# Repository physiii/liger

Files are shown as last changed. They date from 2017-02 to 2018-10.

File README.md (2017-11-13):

# ESP32 Room Sensor

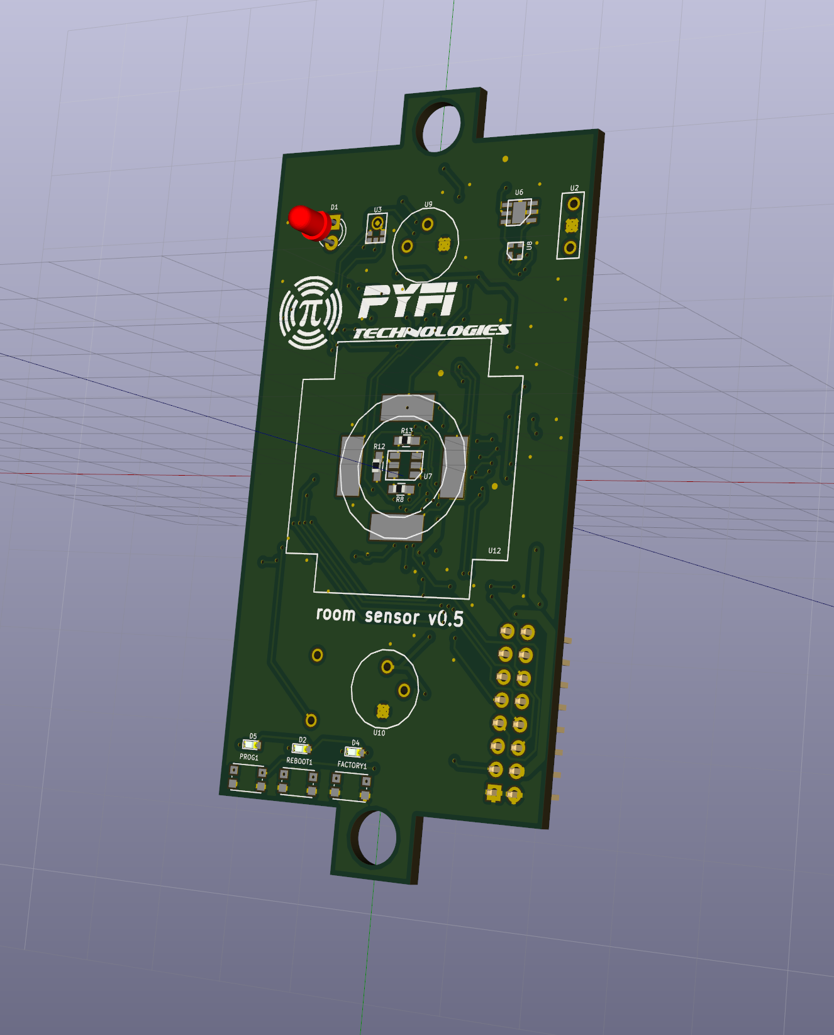
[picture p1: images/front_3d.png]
front


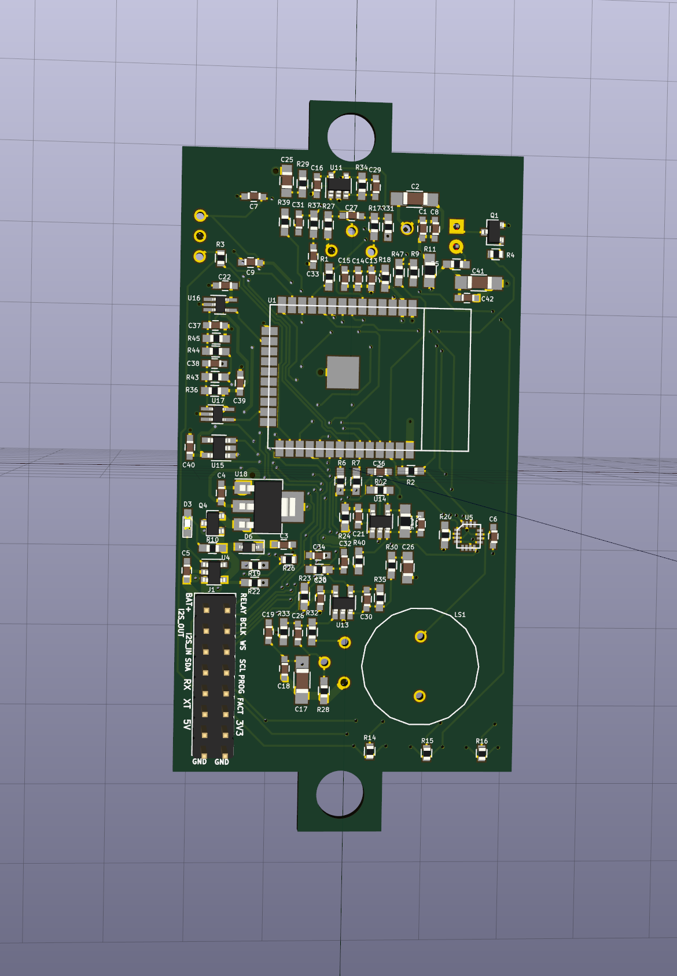
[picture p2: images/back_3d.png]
back


back

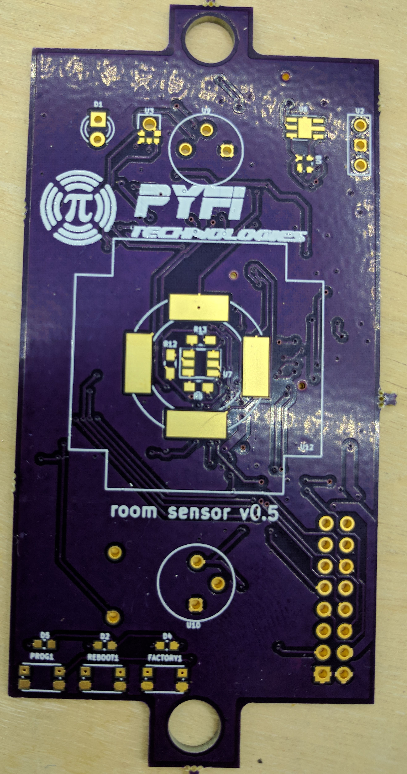
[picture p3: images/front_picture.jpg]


## Schematic Overview
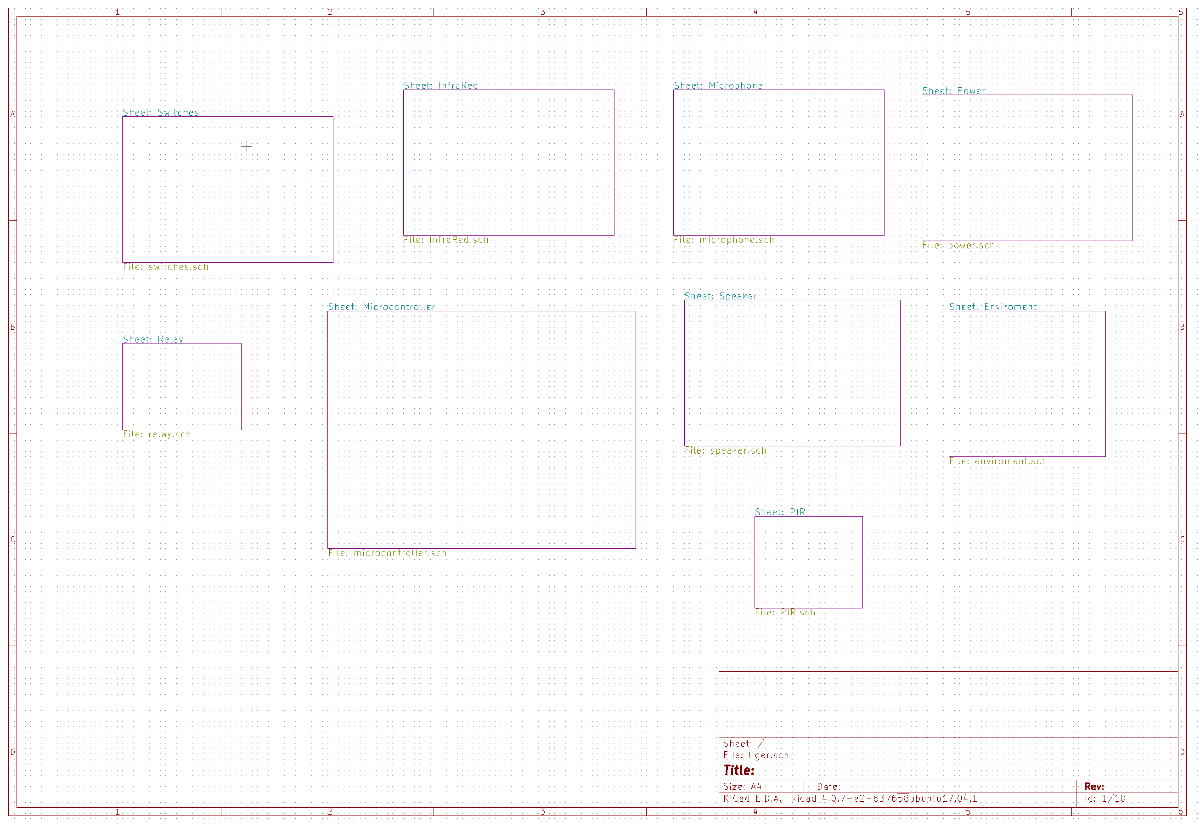
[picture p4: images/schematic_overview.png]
schematic overview


## Motion (PIR) Component
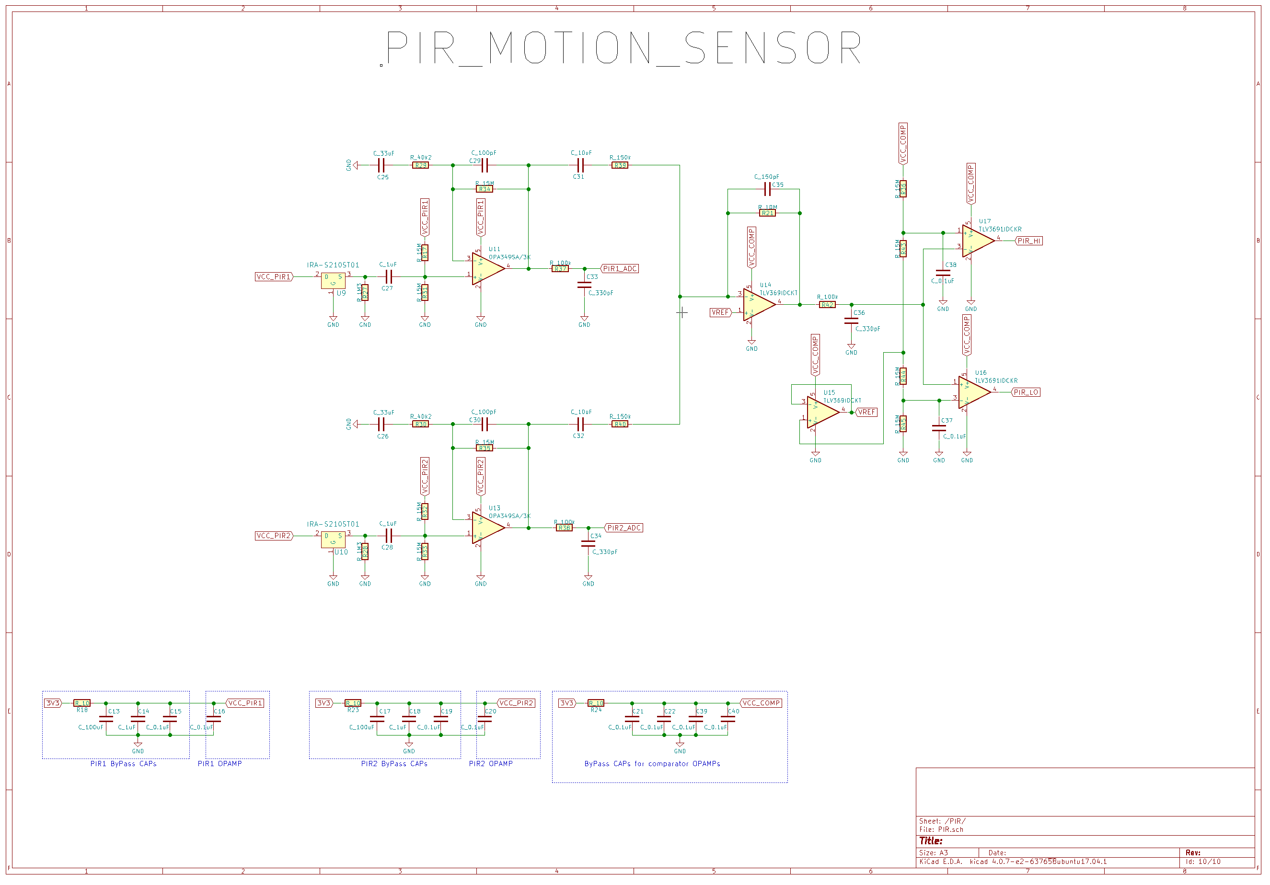
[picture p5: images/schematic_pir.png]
motion


## Features
Motion detection<br>
Audio detection<br>
Media control<br>
Security mode<br>
Light level<br>

## Sensor components
I2S Microphone<br>
Speaker<br>
IR Transmitter<br>
IR Receiver<br>
directional soft button<br>
I2C luminosity<br>
Dual PIR for animal vs human distrinction<br>
Ultrasonic (optional)<br>
Temperature/Humidity<br>

## Applications
Building Automation<br>
Motion Detection<br>
Intrusion Detection<br>
Occupancy Detector<br>
Room Monitors<br>
Pet Detection<br>
Fire Detection<br>
Falling Person Detection<br>

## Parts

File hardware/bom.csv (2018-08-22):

Reference Type | Quantity | Reference | Value | Footprint | Datasheet | Part Number
BT | 1 | BT1, | 18650_Battery_Cell_1043 | Battery:BatteryHolder_Keystone_1042_1x18650 | https://www.digikey.com/product-detail/en/keystone-electronics/1043/36-1043-ND/2745669 | 36-1043-ND
C | 4 | C5,C6,C11,C10, | C_0.1uF | Capacitor_SMD:C_0603_1608Metric_Pad1.05x0.95mm_HandSolder | https://www.digikey.com/product-detail/en/tdk-corporation/C1608X8R1H104K080AB/445-8818-1-ND/3248223 | C1608X8R1H104K080AB
C | 6 | C4,C2,C8,C7,C9,C12, | C_1uF | Capacitor_SMD:C_0603_1608Metric_Pad1.05x0.95mm_HandSolder | https://www.digikey.com/product-detail/en/tdk-corporation/CGA3E1X7R1C105M080AC/445-12540-1-ND/3954206 | CGA3E1X7R1C105M080AC
C | 2 | C3,C1, | C_10uF | Capacitor_SMD:C_0603_1608Metric_Pad1.05x0.95mm_HandSolder | https://www.digikey.com/product-detail/en/samsung-electro-mechanics/CL10A106MP8NNNC/1276-1871-1-ND/3889957 | CL10A106MP8NNNC
D | 1 | D6, | D_Schottky-BAT20JFILM | Diode_SMD:D_SOD-323_HandSoldering | https://www.digikey.com/product-detail/en/stmicroelectronics/BAT20JFILM/497-3381-1-ND/669138 | BAT20JFILM
D | 1 | D1, | LED | LED_THT:LED_D3.0mm | http://www.mouser.com/ds/2/149/QED123-890063.pdf | QED123
D | 3 | D2,D4,D5, | LED-0603-G | LED_SMD:LED_0603_1608Metric_Pad1.05x0.95mm_HandSolder | https://www.digikey.com/product-detail/en/rohm-semiconductor/SML-D12M8WT86/511-1578-1-ND/1641810 | SML-D12M8WT86
D | 1 | D3, | LED-GREEN-LTST-C191GKT | LED_SMD:LED_0603_1608Metric_Pad1.05x0.95mm_HandSolder | https://www.digikey.com/product-detail/en/lite-on-inc/LTST-C191GKT/160-1443-1-ND/386828 | LTST-C191GKT
D | 1 | D7, | WS2812B | LED_SMD:LED_WS2812B_PLCC4_5.0x5.0mm_P3.2mm | https://cdn-shop.adafruit.com/datasheets/WS2812B.pdf
FACTORY | 1 | FACTORY1, | SW_PUSH | Button_Switch_SMD:SW_SPST_KMR2 | http://www.mouser.com/ds/2/60/KMR2_9aug12-25127.pdf | KMR211NG LFS
J | 1 | J1, | Conn_02x08_Odd_Even | Connector_PinHeader_2.54mm:PinHeader_2x08_P2.54mm_Vertical
LS | 1 | LS1, | speaker-CVS-1508 | open-automation:speaker-1508 | http://www.cui.com/product/resource/cvs-1508.pdf | CVS-1508
PROG | 1 | PROG1, | SW_PUSH | Button_Switch_SMD:SW_SPST_KMR2 | http://www.mouser.com/ds/2/60/KMR2_9aug12-25127.pdf | KMR211NG LFS
Q | 1 | Q4, | PMOS-DMG3413L | Package_TO_SOT_SMD:SOT-23 | https://www.digikey.com/product-detail/en/diodes-incorporated/DMG3413L-7/DMG3413L-7DICT-ND/5218387 | DMG3413L-7
Q | 1 | Q1, | Q_NPN_BEC | Package_TO_SOT_SMD:SOT-23 | http://www.onsemi.com/pub/Collateral/MMBT3904LT1-D.PDF | MMBT3904LT1GOSCT-ND
R | 1 | R5, | 36 | Resistor_SMD:R_0603_1608Metric_Pad1.05x0.95mm_HandSolder | http://www.yageo.com.tw/exep/pages/download/literatures/PYu-R_INT-thick_7.pdf | RC0603JR-0736RL
R | 3 | R7,R1,R11, | R_47.5 | Resistor_SMD:R_0603_1608Metric_Pad1.05x0.95mm_HandSolder | https://www.digikey.com/product-detail/en/yageo/RC0603FR-0747R5L/311-47.5HRCT-ND/730201 | RC0603FR-0747R5L
R | 6 | R3,R4,R10,R15,R16,R14, | R_1k | Resistor_SMD:R_0603_1608Metric_Pad1.05x0.95mm_HandSolder | https://www.digikey.com/product-detail/en/yageo/RC0603JR-071KL/311-1.0KGRCT-ND/729624 | RC0603JR-071KL
R | 1 | R19, | R_2k | Resistor_SMD:R_0603_1608Metric_Pad1.05x0.95mm_HandSolder | https://www.digikey.com/product-detail/en/yageo/RC0603JR-072KL/311-2.0KGRCT-ND/729673 | RC0603JR-072KL
R | 4 | R6,R2,R22,R26, | R_10k | Resistor_SMD:R_0603_1608Metric_Pad1.05x0.95mm_HandSolder | https://www.digikey.com/product-detail/en/yageo/RC0603JR-0710KL/311-10KGRCT-ND/729647 | RC0603JR-0710KL
R | 4 | R9,R17,R18,R20, | R_100k | Resistor_SMD:R_0603_1608Metric_Pad1.05x0.95mm_HandSolder | https://www.digikey.com/product-detail/en/yageo/RC0603JR-07100KL/311-100KGRCT-ND/729645 | RC0603JR-07100KL
REBOOT | 1 | REBOOT1, | SW_PUSH | Button_Switch_SMD:SW_SPST_KMR2 | http://www.mouser.com/ds/2/60/KMR2_9aug12-25127.pdf | KMR211NG LFS
U | 1 | U9, | AP2112 | Package_TO_SOT_SMD:SOT-23-5_HandSoldering | https://www.digikey.com/product-detail/en/diodes-incorporated/AP2112K-3.3TRG1/AP2112K-3.3TRG1DICT-ND/4505257 | AP2112K-3.3TRG1
U | 1 | U10, | EKMC1601112 | open-automation:EKMC1601112 | https://www.digikey.com/products/en?keywords=EKMC1601112 | EKMC1601112
U | 1 | U1, | ESP-WROOM-32 | open-automation:ESP-WROOM-32 | http://espressif.com/sites/default/files/documentation/esp-wroom-32_datasheet_en.pdf
U | 1 | U2, | IR-RX-TSOP34438 | open-automation:TSOP75338TR | https://www.digikey.com/product-detail/en/vishay-semiconductor-opto-division/TSOP75338TR/TSOP75338CT-ND/6596741 | TSOP75338TR
U | 1 | U5, | MAX98357AETE+T | open-automation:MAX98357A | https://www.digikey.com/product-detail/en/maxim-integrated/MAX98357AETE-T/MAX98357AETE-TCT-ND/7603777 | MAX98357AETE+T
U | 1 | U4, | MCP73831T | Package_TO_SOT_SMD:SOT-23-5_HandSoldering | https://www.digikey.com/product-detail/en/microchip-technology/MCP73831T-2ACI-OT/MCP73831T-2ACI-OTCT-ND/1979802 | MCP73831T-2ACI/OT
U | 1 | U6, | SI7020-A20 | open-automation:SI7020-A20 | https://www.digikey.com/product-detail/en/silicon-labs/SI7020-A20-GM1R/336-3596-1-ND/5823452 | SI7020-A20-GM1R
U | 1 | U3, | SPH0645LM4H-B | open-automation:SPH0645LM4H-B | https://www.digikey.com/product-detail/en/knowles/SPH0645LM4H-B/423-1405-6-ND/5332436 | SPH0645LM4H-B
U | 1 | U8, | TSL45315CL | open-automation:LIGHT-SENSOR-TSL45315CL | https://www.digikey.com/product-detail/en/ams/TSL45315CL/TSL45315-CLCT-ND/3095326 | TSL45315CL
U | 1 | U12, | soft-button-4x | open-automation:soft-button-4

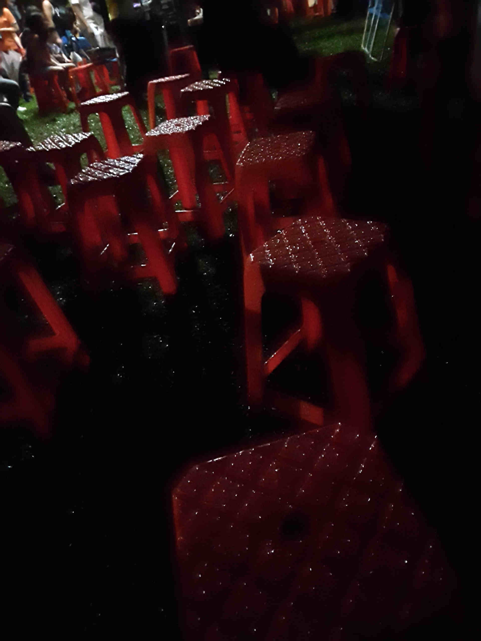
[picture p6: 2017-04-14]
lws-esp32-test-server-demos/components/libwebsockets/plugins/generic-sessions/assets/seats.jpg

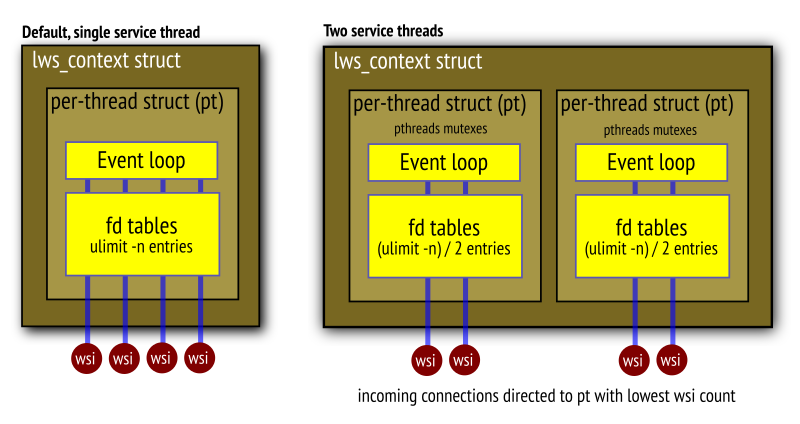
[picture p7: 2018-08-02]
lws-esp32-test-server-demos/components/libwebsockets/doc-assets/lws-smp-ov.png

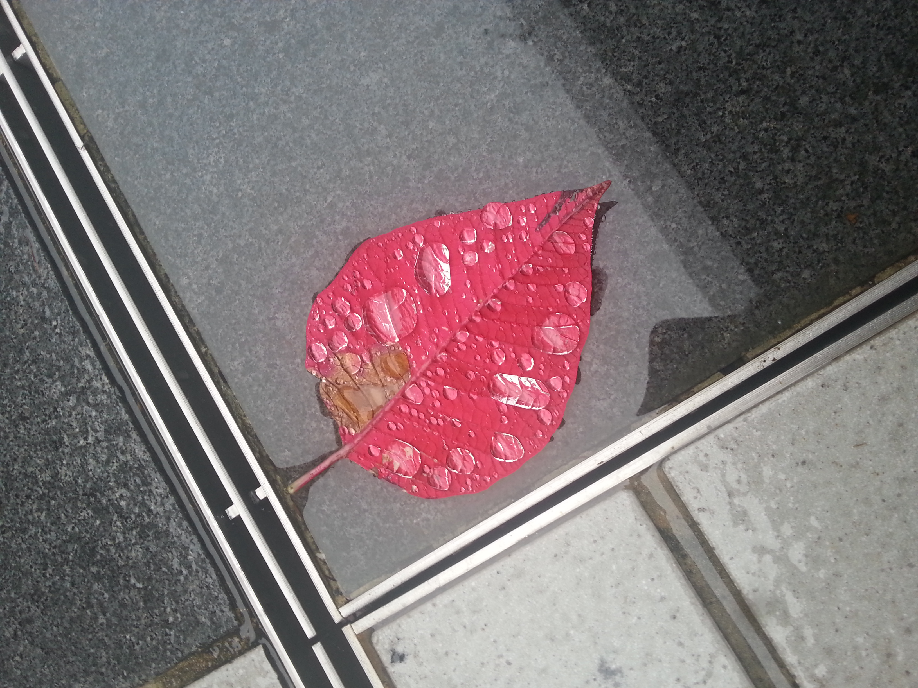
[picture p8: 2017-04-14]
lws-esp32-test-server-demos/components/libwebsockets/minimal-examples/http-server/minimal-http-server-eventlib-demos/mount-origin/leaf.jpg

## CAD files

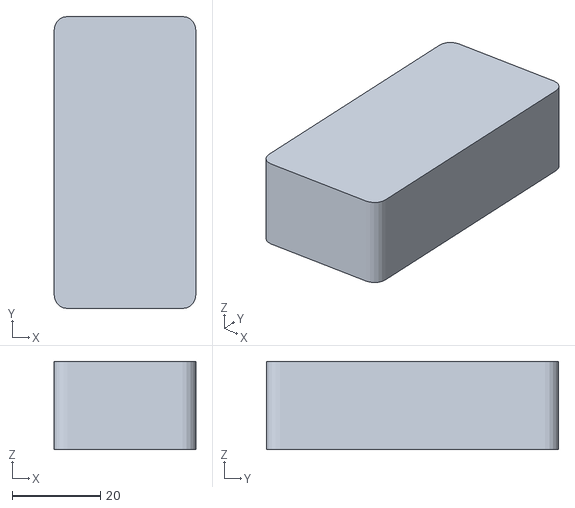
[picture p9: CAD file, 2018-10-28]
model/test_block.stl
32.0 x 66.0 x 20.0

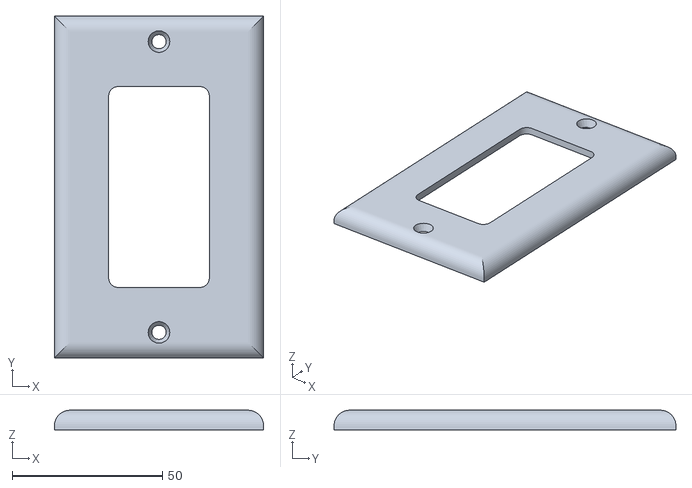
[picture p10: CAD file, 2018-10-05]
model/GFCI_WallPlate_SingleGang.stl
69.6 x 113.8 x 6.54

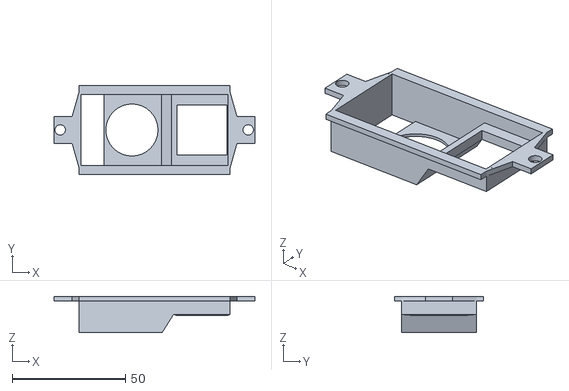
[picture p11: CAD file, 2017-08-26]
model/liger.stl
88.7 x 39.3 x 16.0

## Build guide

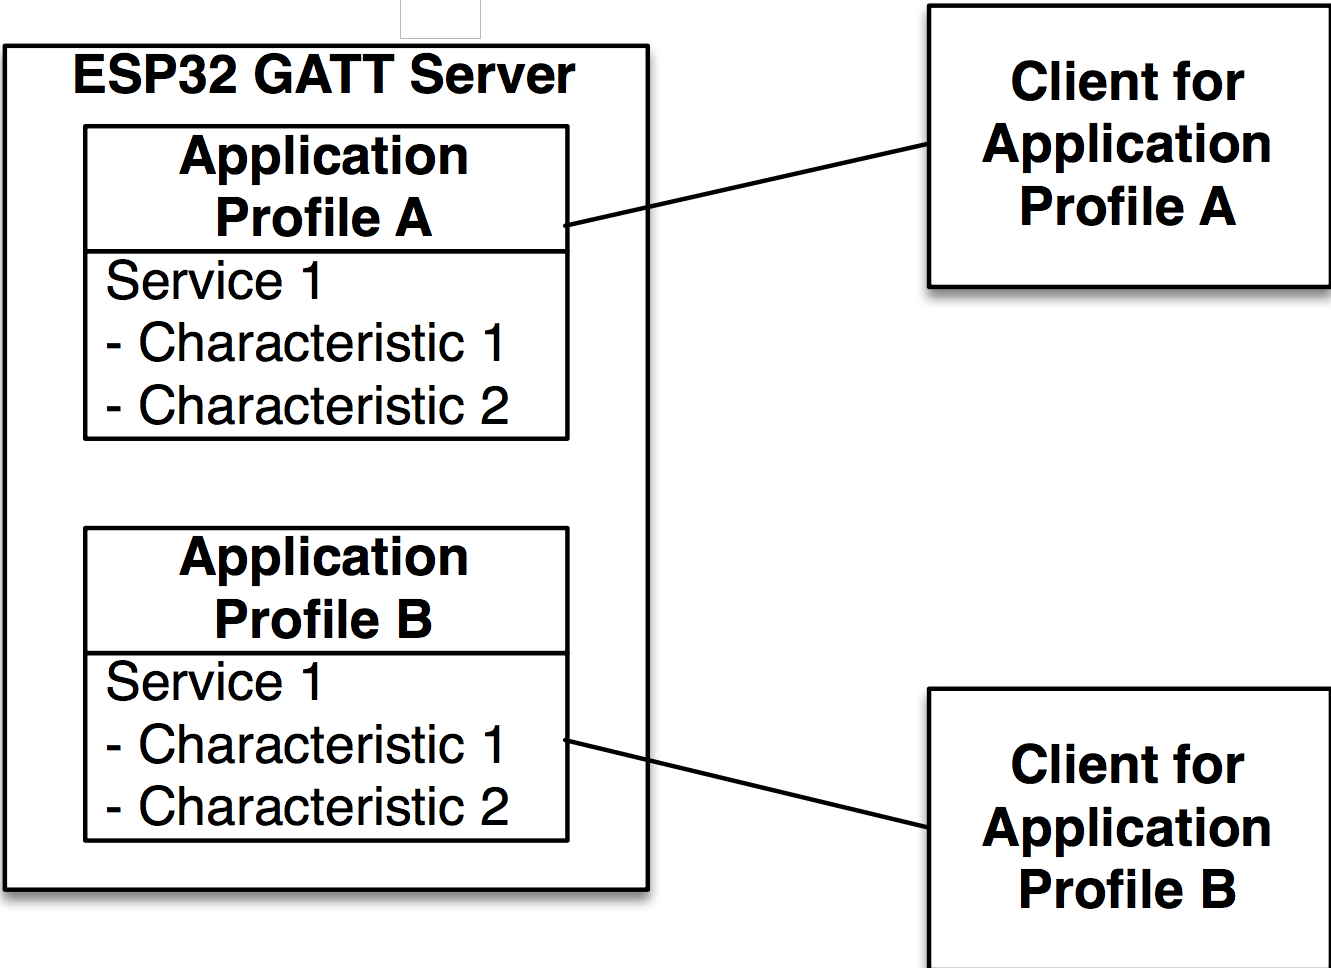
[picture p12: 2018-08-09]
code/bt_server/tutorial/image/GATT_Server_Figure_1.png

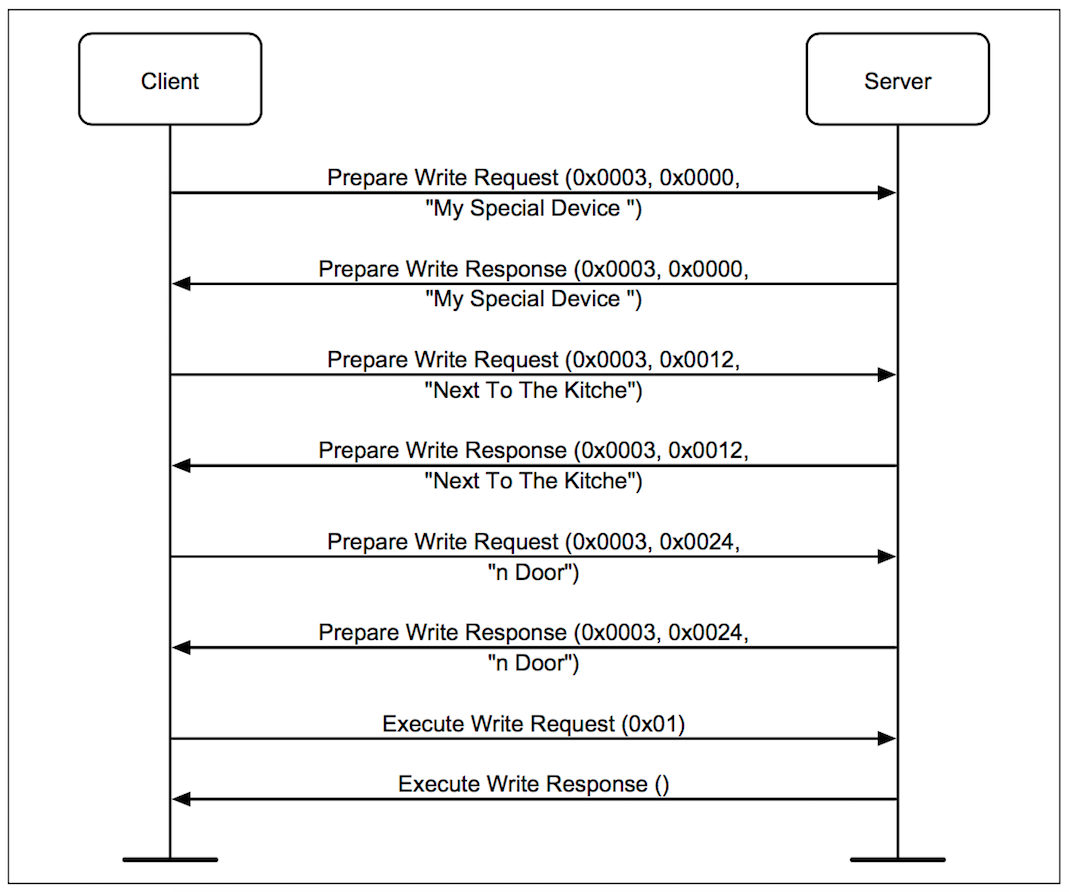
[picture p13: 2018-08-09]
code/bt_server/tutorial/image/GATT_Server_Figure_2.png

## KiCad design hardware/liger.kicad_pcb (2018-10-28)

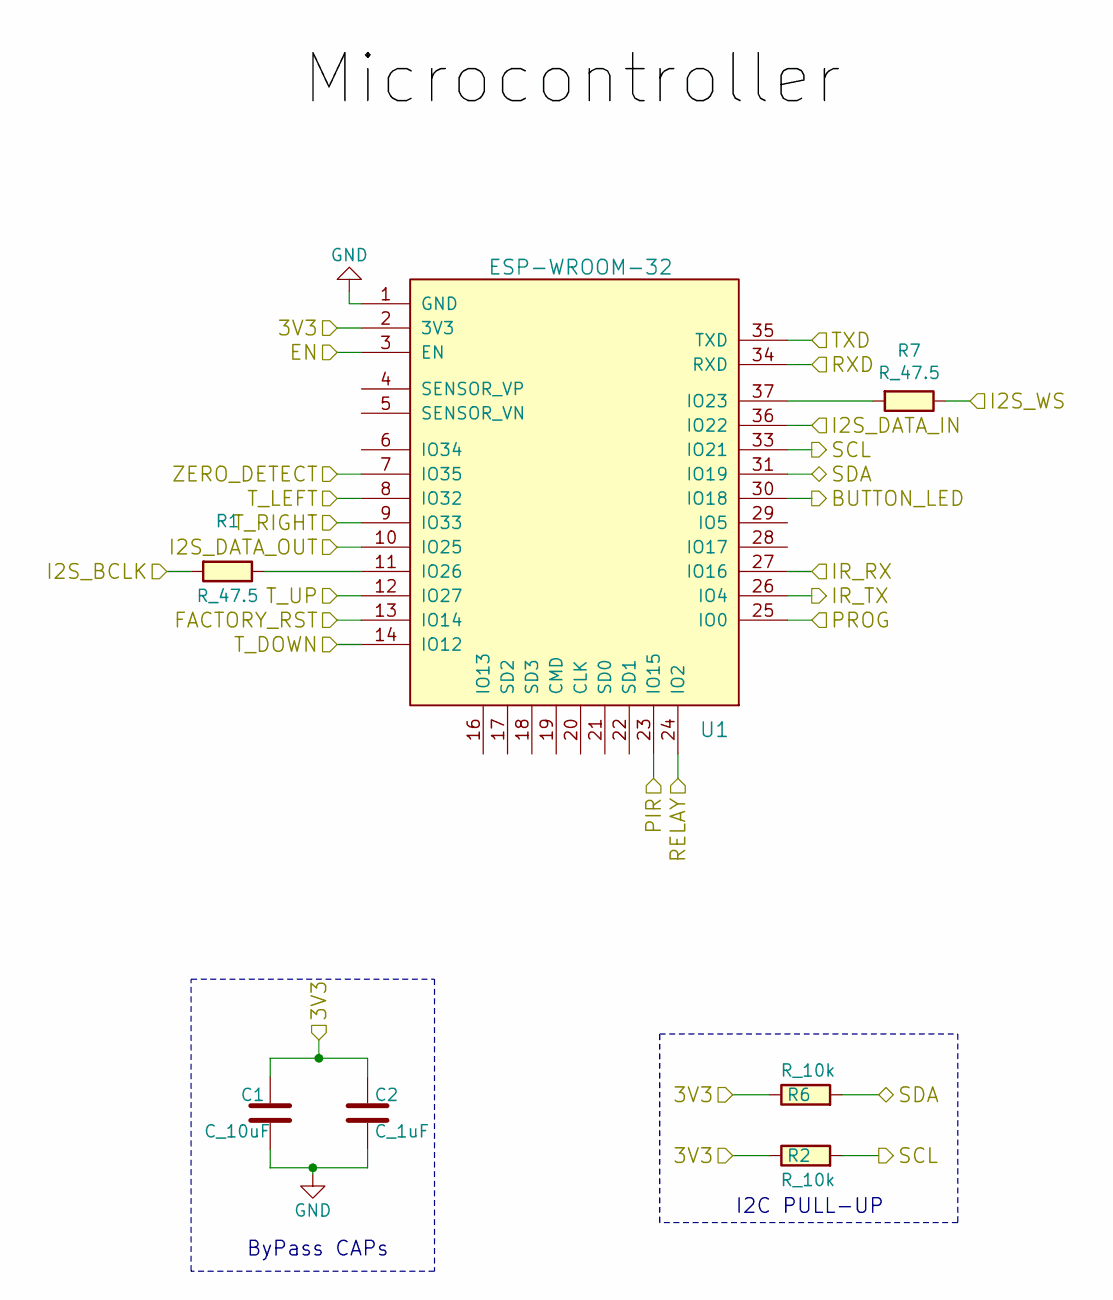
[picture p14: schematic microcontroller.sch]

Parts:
C1: C_10uF; C_0603_1608Metric_Pad1.05x0.95mm_HandSolder; Part Number CL10A106MP8NNNC
C2: C_1uF; C_0603_1608Metric_Pad1.05x0.95mm_HandSolder; Part Number CL10B105KP8NNNC
R1, R7: R_47.5; R_0603_1608Metric_Pad1.05x0.95mm_HandSolder; Part Number ERJ-3EKF47R5V
R2, R6: R_10k; R_0603_1608Metric_Pad1.05x0.95mm_HandSolder; Part Number MCT06030C1002FP500
U1: ESP-WROOM-32

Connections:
/3V3: C1.1, C2.1, R2.1, R6.1, U1.2 (3V3); also elsewhere on the board
/BUTTON_LED: U1.30 (IO18); also elsewhere on the board
/EN: U1.3 (EN); also elsewhere on the board
/FACTORY_RST: U1.13 (IO14); also elsewhere on the board
/I2S_BCLK: R1.2; also elsewhere on the board
/I2S_DATA_IN: U1.36 (IO22); also elsewhere on the board
/I2S_DATA_OUT: U1.10 (IO25); also elsewhere on the board
/I2S_WS: R7.1; also elsewhere on the board
/IR_RX: U1.27 (IO16); also elsewhere on the board
/IR_TX: U1.26 (IO4); also elsewhere on the board
/PIR: U1.23 (IO15); also elsewhere on the board
/PROG: U1.25 (IO0); also elsewhere on the board
/RELAY: U1.24 (IO2); also elsewhere on the board
/RXD: U1.34 (RXD); also elsewhere on the board
/SCL: R2.2, U1.33 (IO21); also elsewhere on the board
/SDA: R6.2, U1.31 (IO19); also elsewhere on the board
/TXD: U1.35 (TXD); also elsewhere on the board
/T_DOWN: U1.14 (IO12); also elsewhere on the board
/T_LEFT: U1.8 (IO32); also elsewhere on the board
/T_RIGHT: U1.9 (IO33); also elsewhere on the board
/T_UP: U1.12 (IO27); also elsewhere on the board
/ZERO_DETECT: U1.7 (IO35); also elsewhere on the board
GND: C1.2, C2.2, U1.1 (GND); also elsewhere on the board
unnamed: R1.1, U1.11 (IO26)
unnamed: R7.2, U1.37 (IO23)

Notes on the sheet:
ByPass CAPs
I2C PULL-UP

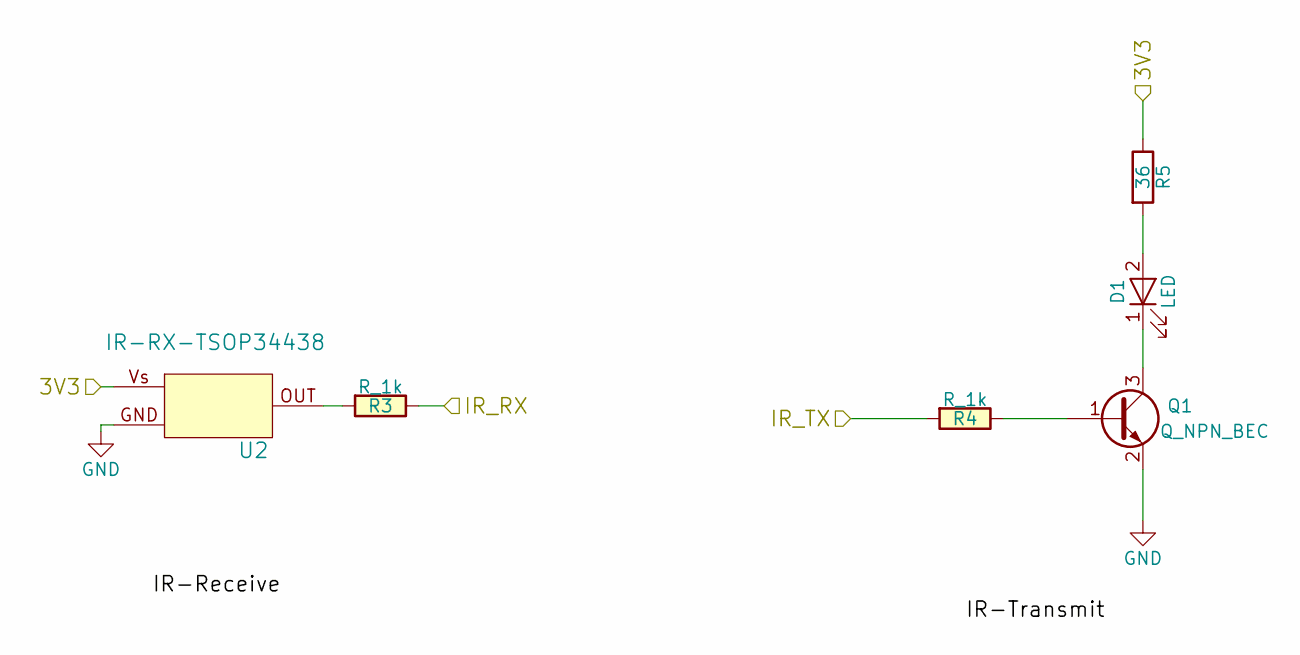
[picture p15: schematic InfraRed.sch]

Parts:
D1: LED; LED_D3.0mm; Part Number QED123
Q1: Q_NPN_BEC; SOT-23; Part Number MMBT3904-TP
R3, R4: R_1k; R_0603_1608Metric_Pad1.05x0.95mm_HandSolder; Part Number ESR03EZPJ102
R5: 36; R_0603_1608Metric_Pad1.05x0.95mm_HandSolder; Part Number RMCF0603FT36R0
U2: IR-RX-TSOP34438; TSOP75338TR; Part Number TSOP75338TR

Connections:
/3V3: R5.1, U2.Vs; also elsewhere on the board
/IR_RX: R3.1; also elsewhere on the board
/IR_TX: R4.2; also elsewhere on the board
GND: Q1.2 (E), U2.GND; also elsewhere on the board
unnamed: D1.1 (K), Q1.3 (C)
unnamed: D1.2 (A), R5.2
unnamed: Q1.1 (B), R4.1
unnamed: R3.2, U2.OUT

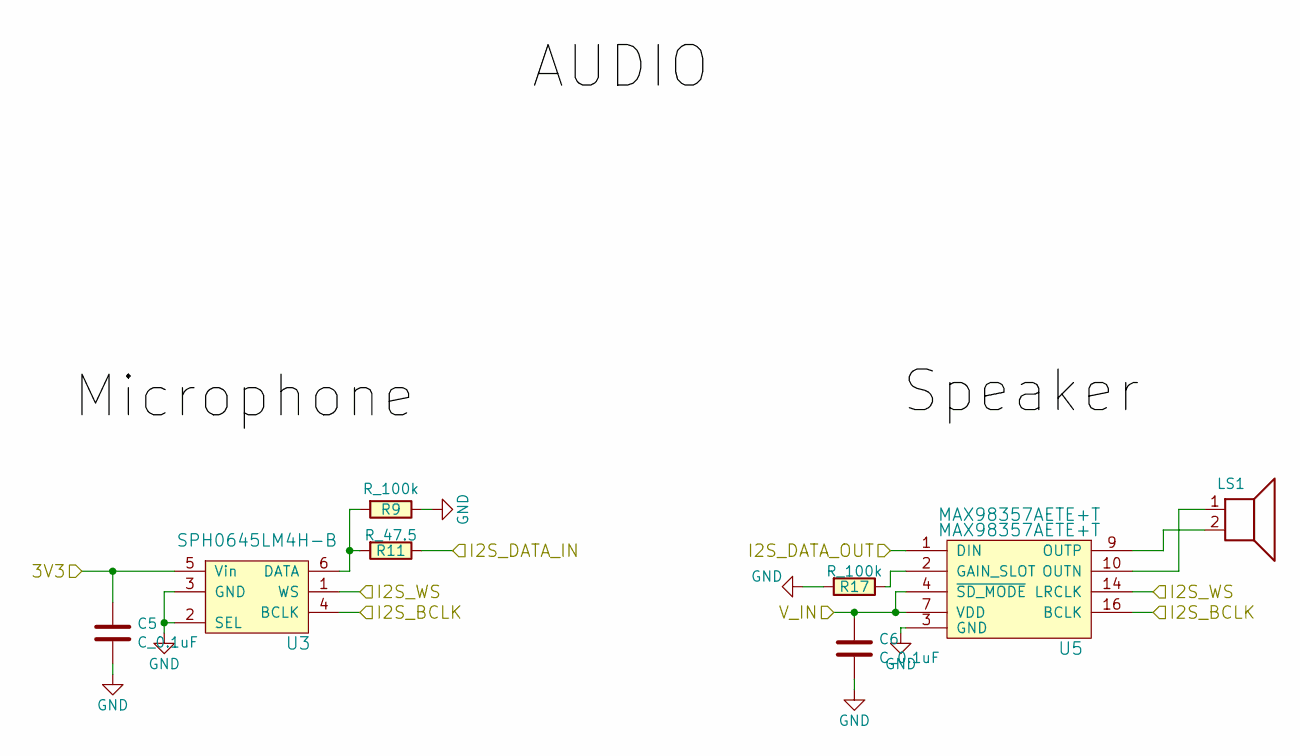
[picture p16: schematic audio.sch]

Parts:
C5, C6: C_0.1uF; C_0603_1608Metric_Pad1.05x0.95mm_HandSolder; Part Number CL10F104ZO8NNNC
LS1: speaker-CVS-1508; speaker-1508; Part Number CVS-1508
R9, R17: R_100k; R_0603_1608Metric_Pad1.05x0.95mm_HandSolder; Part Number ERA-3AEB104V
R11: R_47.5; R_0603_1608Metric_Pad1.05x0.95mm_HandSolder; Part Number ERJ-3EKF47R5V
U3: SPH0645LM4H-B; Part Number SPH0645LM4H-B
U5: MAX98357AETE+T; MAX98357A; Part Number MAX98357AETE+T

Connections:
/3V3: C5.1, U3.5 (Vin); also elsewhere on the board
/I2S_BCLK: U3.4 (BCLK), U5.16 (BCLK); also elsewhere on the board
/I2S_DATA_IN: R11.1; also elsewhere on the board
/I2S_DATA_OUT: U5.1 (DIN); also elsewhere on the board
/I2S_WS: U3.1 (WS), U5.14 (LRCLK); also elsewhere on the board
/V_IN: C6.1, U5.4 (~SD_MODE), U5.7 (VDD); also elsewhere on the board
GND: C5.2, C6.2, R9.1, R17.2, U3.2 (SEL), U3.3 (GND), U5.3 (GND); also elsewhere on the board
unnamed: LS1.1, U5.10 (OUTN)
unnamed: LS1.2, U5.9 (OUTP)
unnamed: R9.2, R11.2, U3.6 (DATA)
unnamed: R17.1, U5.2 (GAIN_SLOT)

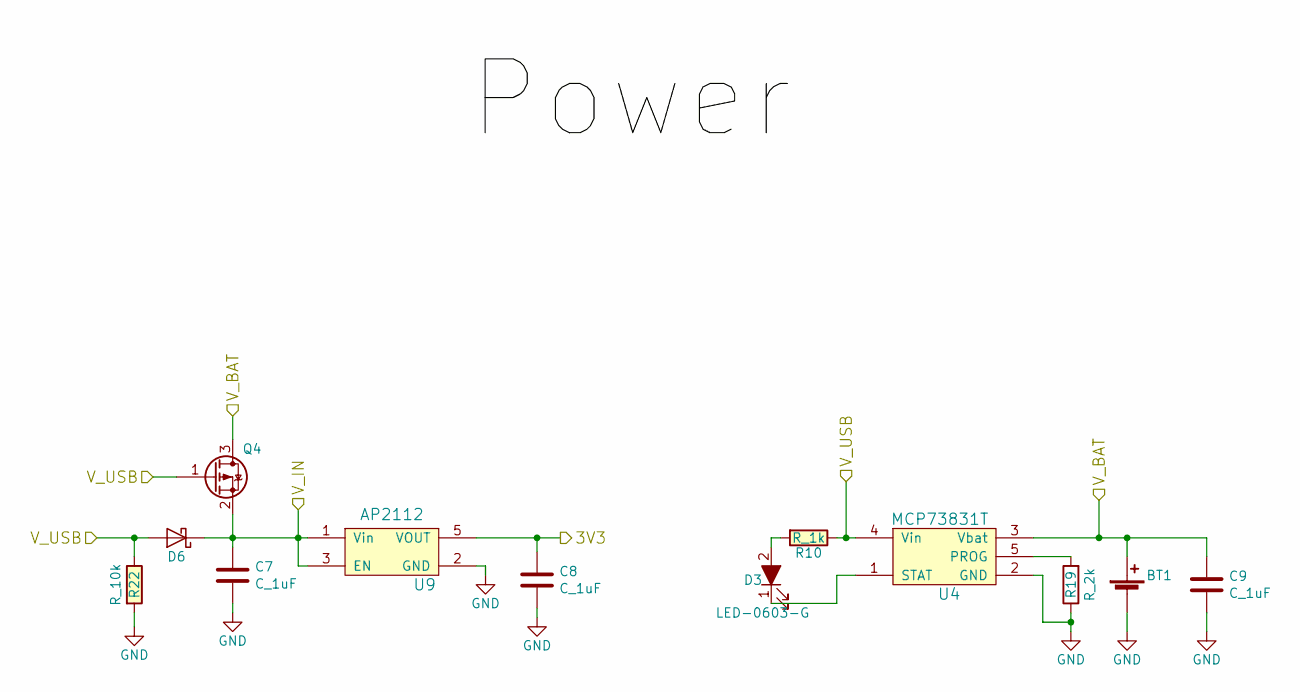
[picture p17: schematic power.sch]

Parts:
BT1: 18650_Battery_Cell_1043; BatteryHolder_Keystone_1042_1x18650; Part Number 36-1043-ND
C7, C8, C9: C_1uF; C_0603_1608Metric_Pad1.05x0.95mm_HandSolder; Part Number CL10B105KP8NNNC
D3: LED-0603-G; LED_0603_1608Metric_Pad1.05x0.95mm_HandSolder; Part Number SML-D12M8WT86
D6: D_Schottky-BAT20JFILM; D_SOD-323_HandSoldering; Part Number BAT20JFILM
Q4: PMOS-DMG3413L; SOT-23; Part Number DMG3413L-7
R10: R_1k; R_0603_1608Metric_Pad1.05x0.95mm_HandSolder; Part Number ESR03EZPJ102
R19: R_2k; R_0603_1608Metric_Pad1.05x0.95mm_HandSolder; Part Number ERA-3AEB202V
R22: R_10k; R_0603_1608Metric_Pad1.05x0.95mm_HandSolder; Part Number MCT06030C1002FP500
U4: MCP73831T; SOT-23-5_HandSoldering; Part Number MCP73831T-2ACI/OT
U9: AP2112; SOT-23-5_HandSoldering; Part Number AP2112K-3.3TRG1

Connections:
/3V3: C8.1, U9.5 (VOUT); also elsewhere on the board
/V_BAT: BT1.1 (+), C9.1, Q4.3 (D), U4.3 (Vbat); also elsewhere on the board
/V_IN: C7.1, D6.1 (K), Q4.2 (S), U9.1 (Vin), U9.3 (EN); also elsewhere on the board
/V_USB: D6.2 (A), Q4.1 (G), R10.1, R22.1, U4.4 (Vin); also elsewhere on the board
GND: BT1.2 (-), C7.2, C8.2, C9.2, R19.1, R22.2, U4.2 (GND), U9.2 (GND); also elsewhere on the board
unnamed: D3.1 (K), U4.1 (STAT)
unnamed: D3.2 (A), R10.2
unnamed: R19.2, U4.5 (PROG)

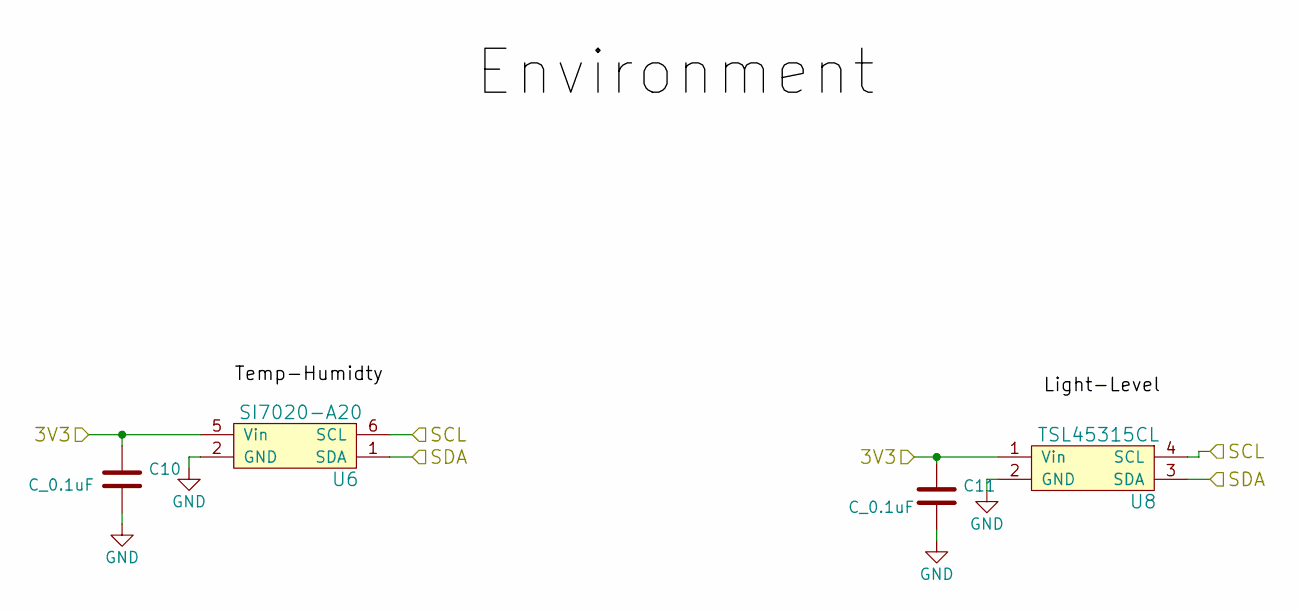
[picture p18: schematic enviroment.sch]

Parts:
C10, C11: C_0.1uF; C_0603_1608Metric_Pad1.05x0.95mm_HandSolder; Part Number CL10F104ZO8NNNC
U6: SI7020-A20; Part Number SI7020-A20-GM1R
U8: TSL45315CL; LIGHT-SENSOR-TSL45315CL; Part Number TSL45315CL

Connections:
/3V3: C10.1, C11.1, U6.5 (Vin), U8.1 (Vin); also elsewhere on the board
/SCL: U6.6 (SCL), U8.4 (SCL); also elsewhere on the board
/SDA: U6.1 (SDA), U8.3 (SDA); also elsewhere on the board
GND: C10.2, C11.2, U6.2 (GND), U8.2 (GND); also elsewhere on the board

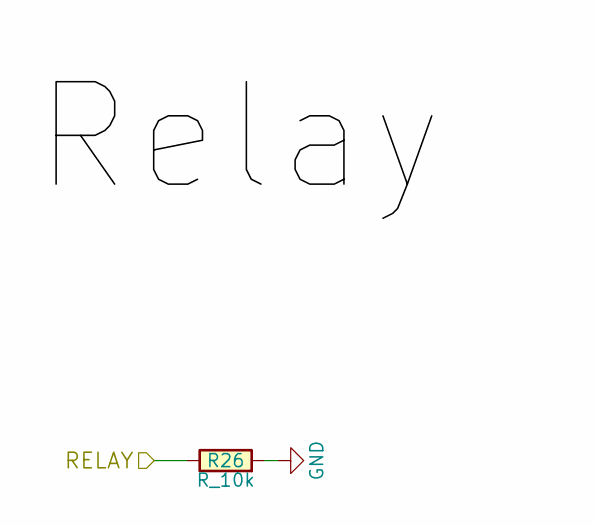
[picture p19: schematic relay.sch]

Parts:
R26: R_10k; R_0603_1608Metric_Pad1.05x0.95mm_HandSolder; Part Number MCT06030C1002FP500

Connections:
/RELAY: R26.1; also elsewhere on the board
GND: R26.2; also elsewhere on the board

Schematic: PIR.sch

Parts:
C3: C_0.1uF; C_0603_1608Metric_Pad1.05x0.95mm_HandSolder; Part Number CL10F104ZO8NNNC
C4: C_100pF; C_0603_1608Metric_Pad1.05x0.95mm_HandSolder; Part Number 06035A101FAT2A
R8: R_47.5; R_0603_1608Metric_Pad1.05x0.95mm_HandSolder; Part Number ERJ-3EKF47R5V
R20: R_100k; R_0603_1608Metric_Pad1.05x0.95mm_HandSolder; Part Number ERA-3AEB104V
U7: PYQ2898; TO-5-3; Part Number PYQ2898

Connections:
/3V3: C3.1; also elsewhere on the board
/PIR: R8.1, R20.2; also elsewhere on the board
GND: C3.2, C4.2, R20.1; also elsewhere on the board
unnamed 27: C4.1, R8.2; also elsewhere on the board

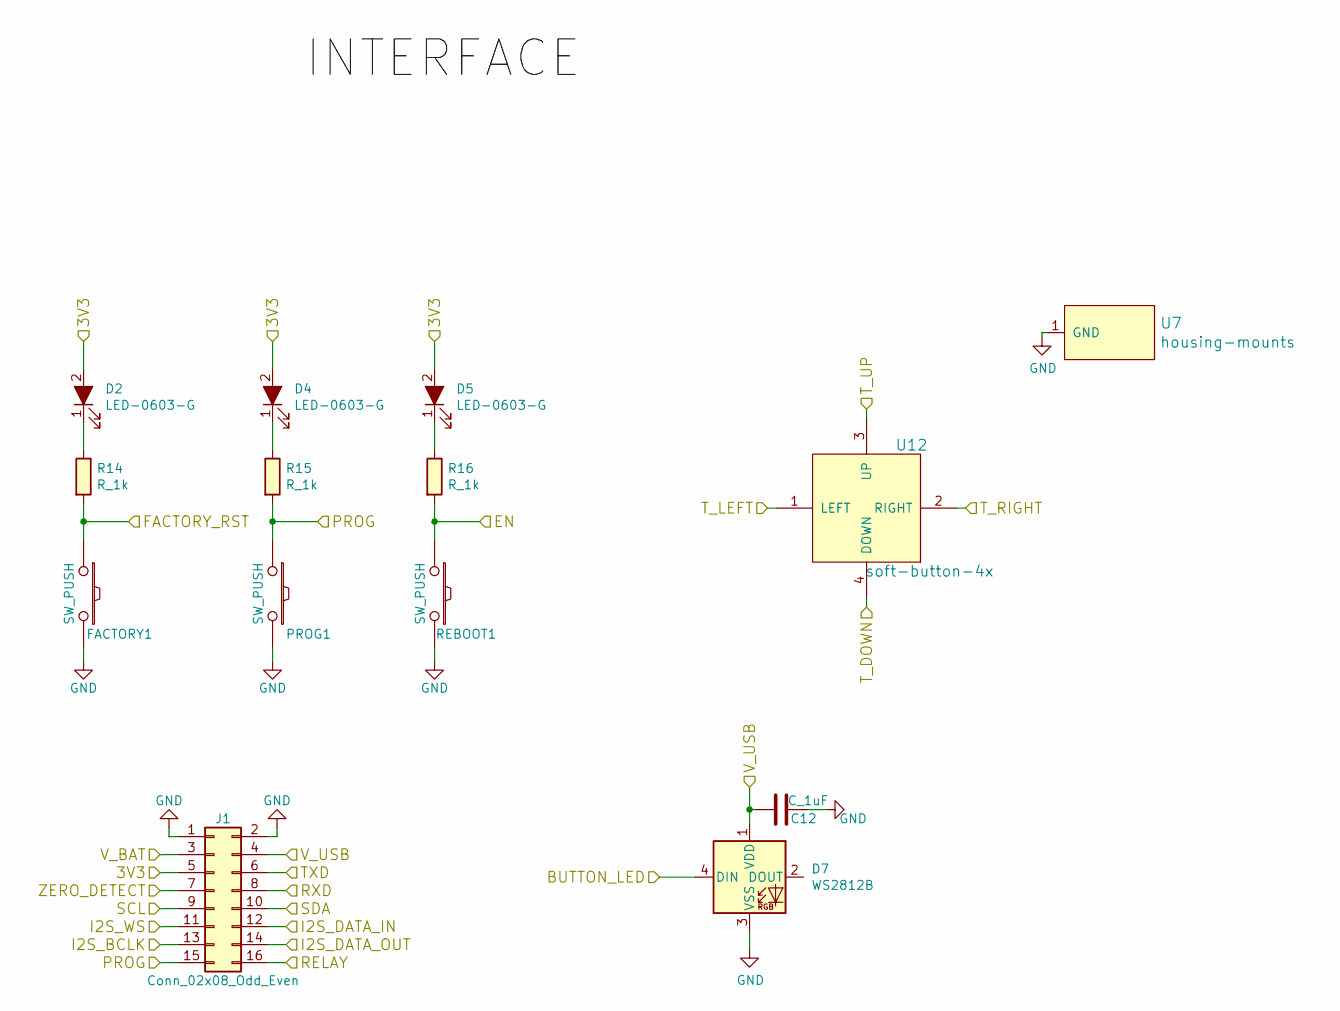
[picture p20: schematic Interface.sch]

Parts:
C12: C_1uF; C_0603_1608Metric_Pad1.05x0.95mm_HandSolder; Part Number CL10B105KP8NNNC
D2, D4, D5: LED-0603-G; LED_0603_1608Metric_Pad1.05x0.95mm_HandSolder; Part Number SML-D12M8WT86
D7: WS2812B; LED_WS2812B_PLCC4_5.0x5.0mm_P3.2mm
FACTORY1: SW_PUSH; SW_SPST_KMR2; Part Number KMR211NG LFS
J1: Conn_02x08_Odd_Even; PinHeader_2x08_P2.54mm_Vertical
PROG1: SW_PUSH; SW_SPST_KMR2; Part Number KMR211NG LFS
R14, R15, R16: R_1k; R_0603_1608Metric_Pad1.05x0.95mm_HandSolder; Part Number ESR03EZPJ102
REBOOT1: SW_PUSH; SW_SPST_KMR2; Part Number KMR211NG LFS
U7: housing-mounts; generic-housing-mounts-md
U12: soft-button-4x; soft-button-4

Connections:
/3V3: D2.2 (A), D4.2 (A), D5.2 (A), J1.5; also elsewhere on the board
/BUTTON_LED: D7.4 (DIN); also elsewhere on the board
/EN: R16.2, REBOOT1.1; also elsewhere on the board
/FACTORY_RST: FACTORY1.1, R14.2; also elsewhere on the board
/I2S_BCLK: J1.13; also elsewhere on the board
/I2S_DATA_OUT: J1.14; also elsewhere on the board
/I2S_WS: J1.11; also elsewhere on the board
/IS2_DATA_IN: J1.12
/PROG: J1.15, PROG1.1, R15.2; also elsewhere on the board
/RELAY: J1.16; also elsewhere on the board
/RXD: J1.8; also elsewhere on the board
/SCL: J1.9; also elsewhere on the board
/SDA: J1.10; also elsewhere on the board
/TXD: J1.6; also elsewhere on the board
/T_DOWN: U12.4 (DOWN); also elsewhere on the board
/T_LEFT: U12.1 (LEFT); also elsewhere on the board
/T_RIGHT: U12.2 (RIGHT); also elsewhere on the board
/T_UP: U12.3 (UP); also elsewhere on the board
/V_BAT: J1.3; also elsewhere on the board
/V_USB: C12.2, D7.1 (VDD), J1.4; also elsewhere on the board
/ZERO_DETECT: J1.7; also elsewhere on the board
GND: C12.1, D7.3 (VSS), FACTORY1.2, J1.1, J1.2, PROG1.2, REBOOT1.2, U7.1; also elsewhere on the board
unnamed: D2.1 (K), R14.1
unnamed: D4.1 (K), R15.1
unnamed: D5.1 (K), R16.1

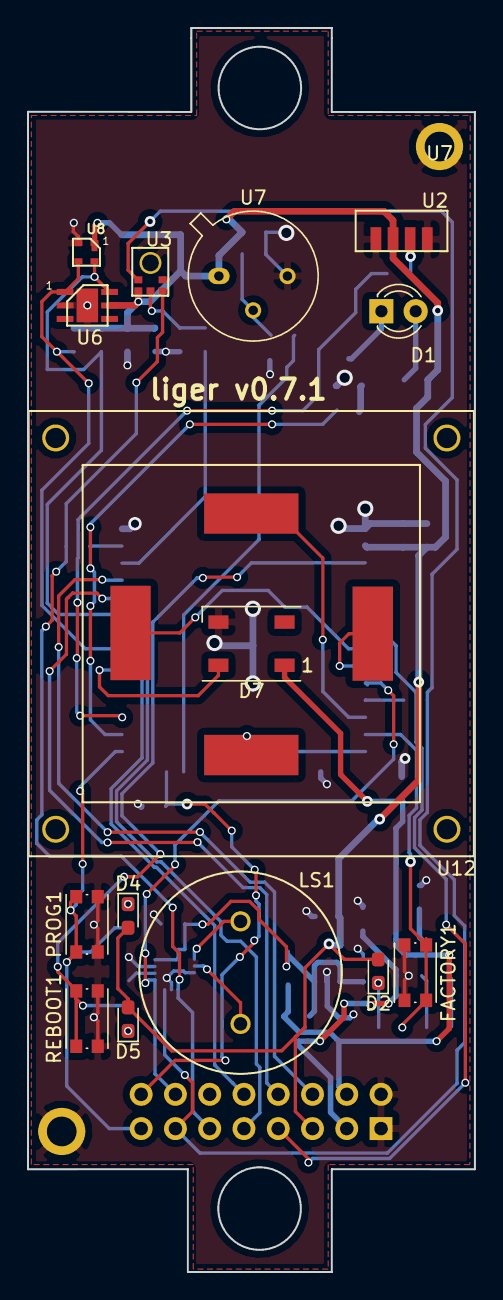
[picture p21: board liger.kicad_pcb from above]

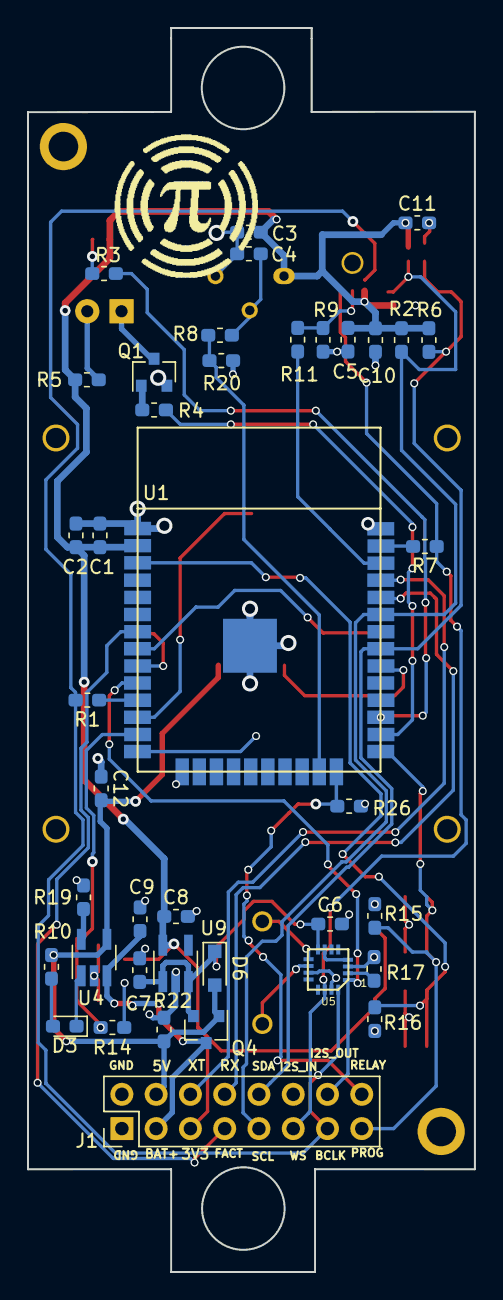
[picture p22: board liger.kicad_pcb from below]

Board: 2 copper layers, 33.1 x 92.2 mm, 57 parts (41 on the bottom side), 43 nets.

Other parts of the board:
LOGO: pyfi_symbol
U7#2: PYQ2898; TO-5-3

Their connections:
/3V3: U7#2.1; also elsewhere on the board
GND: U7#2.3; also elsewhere on the board
unnamed 27: U7#2.2; also elsewhere on the board

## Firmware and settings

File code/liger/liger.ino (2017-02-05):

/*
   Copyright (c) 2015, Majenko Technologies
   All rights reserved.

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
 * * Neither the name of Majenko Technologies nor the names of its
     contributors may be used to endorse or promote products derived fro
     this software without specific prior written permission.

   THIS SOFTWARE IS PROVIDED BY THE COPYRIGHT HOLDERS AND CONTRIBUTORS "AS IS" AND
   ANY EXPRESS OR IMPLIED WARRANTIES, INCLUDING, BUT NOT LIMITED TO, THE IMPLIED
   WARRANTIES OF MERCHANTABILITY AND FITNESS FOR A PARTICULAR PURPOSE ARE
   DISCLAIMED. IN NO EVENT SHALL THE COPYRIGHT HOLDER OR CONTRIBUTORS BE LIABLE FOR
   ANY DIRECT, INDIRECT, INCIDENTAL, SPECIAL, EXEMPLARY, OR CONSEQUENTIAL DAMAGES
   (INCLUDING, BUT NOT LIMITED TO, PROCUREMENT OF SUBSTITUTE GOODS OR SERVICES;
   LOSS OF USE, DATA, OR PROFITS; OR BUSINESS INTERRUPTION) HOWEVER CAUSED AND ON
   ANY THEORY OF LIABILITY, WHETHER IN CONTRACT, STRICT LIABILITY, OR TORT
   (INCLUDING NEGLIGENCE OR OTHERWISE) ARISING IN ANY WAY OUT OF THE USE OF THIS
   SOFTWARE, EVEN IF ADVISED OF THE POSSIBILITY OF SUCH DAMAGE.
*/

/* Create a WiFi access point and provide a web server on it. */

#include <ESP8266WiFi.h>
#include <WiFiClient.h>
#include <Ticker.h>
#include <ESP8266WebServer.h>
#include <ESP8266mDNS.h>
#include <EEPROM.h>
#include <Arduino.h>
#include <Time.h>
#include <ESP8266WiFi.h>
#include <ESP8266WiFiMulti.h>
#include <WebSocketsClient.h>
#include <Hash.h>
#include <IRremoteESP8266.h>
#include <IRremoteInt.h>
#include <ArduinoJson.h>
#include <WiFiUdp.h>
#include <ArduinoOTA.h>
#include "ESP8266httpUpdate.h"

ESP8266WiFiMulti WiFiMulti;
WebSocketsClient webSocket;
#define TRIGGER 12
#define ECHO    14
#define RELAY   15
#define MIC     A0
#define PIR     16
#define IR_RX   4
#define IR_TX   14
#define SW      13
#define SW_LED  5
 
#define cbi(sfr, bit) (_SFR_BYTE(sfr) &= ~_BV(bit))
#define sbi(sfr, bit) (_SFR_BYTE(sfr) |= _BV(bit))
int numSamples=0;
long t, t0;

decode_results results;
/** the current address in the EEPROM (i.e. which byte we're going to write to next) **/
int addr = 0;
const char *ap_ssid = "room_sensor ";
const char *io_relay = "98.168.142.41";
const char *version_number = "room_sensor_v0.1";
int io_port = 4000;
//const char *ap_password = "password";
char html[5000] = "";
bool scan_complete = false;
bool ap_started = false;
bool connect_to_ap = false;
bool got_token = false;
bool wsConnected = false;
const int led = 13;
int address = 0;
int ssid_ptr = 0;
int password_addr = 0;
int sum = 0;
int sum_total = 0;
int count = 0;
int time_delta = 0;
byte value;
long duration, distance, old_distance, distance_delta, distance_buffer, distance_sum;
const int bufferSize = 2000;
uint8_t analog_data[bufferSize];
char analog_data_str[bufferSize] = "";
//uint8_t analog_buffer[44100];
byte mac[6];
char token[200] = "init";
char current_ssid[100];
bool isConnected = false;
char distance_str[50] = "";
char mac_addr[20] = "";
char response[200] = "";
char token_req[200] = "";
char is_token[130] = "";
char response_token[130] = "";
char ssid_found[50] = "";
char ssid[50] = "";
char new_password[50] = "";
char password[50] = "";
char count_str[50] = "";
char message[2100] = "";
char uptime[10] = "";
char now_str[10] = "";
char magnitude_str[50] = "";
char motion_status_str[50] = "";
char PIR_width_str[50] = "";
String motion_status = "No Motion Detected";
int previous_uptime;
char local_ip[20] = "init";
int response_delay = 0;
int response_time = 0;
int png_time = 0;
int PIR_t = 0;
int PIR_t0 = millis();
int PIR_count = 0;
int threshold = 1000;
bool detected_pulse = false;
bool motion_started = false;
ESP8266WebServer server(80);
int ap_connect();
void start_ap();
void sendIR(unsigned int ir_code);



// ---------------------------------------------------------------- //
// -------------------------- OTA_update -------------------------- //
// ---------------------------------------------------------------- //
void OTA_update() {
  // Port defaults to 8266
  // ArduinoOTA.setPort(8266);

  // Hostname defaults to esp8266-[ChipID]
  // ArduinoOTA.setHostname("myesp8266");

  // No authentication by default
  ArduinoOTA.setPassword((const char *)"qweasdzxc");

  ArduinoOTA.onStart([]() {
    Serial.println("Start");
  });
  ArduinoOTA.onEnd([]() {
    Serial.println("\nEnd");
  });
  ArduinoOTA.onProgress([](unsigned int progress, unsigned int total) {
    Serial.printf("Progress: %u%%\r", (progress / (total / 100)));
  });
  ArduinoOTA.onError([](ota_error_t error) {
    Serial.printf("Error[%u]: ", error);
    if (error == OTA_AUTH_ERROR) Serial.println("Auth Failed");
    else if (error == OTA_BEGIN_ERROR) Serial.println("Begin Failed");
    else if (error == OTA_CONNECT_ERROR) Serial.println("Connect Failed");
    else if (error == OTA_RECEIVE_ERROR) Serial.println("Receive Failed");
    else if (error == OTA_END_ERROR) Serial.println("End Failed");
  });
  ArduinoOTA.begin();
}

void http_update() {
  /*t_httpUpdate_return ret = ESPhttpUpdate.update("24.253.223.242", 8080, "/open-automation.org/php/device_update.php", "liger v0.1");
  switch(ret) {
    case HTTP_UPDATE_FAILED:
        Serial.println("[update] Update failed.");
        break;
    case HTTP_UPDATE_NO_UPDATES:
        Serial.println("[update] Update no Update.");
        break;
    case HTTP_UPDATE_OK:
        Serial.println("[update] Update ok."); // may not called we reboot the ESP
        break;
  }*/
  //char update_url[100] = "/open-automation.org/downloads/";
  //strcat(update_url,version_number);
  ESPhttpUpdate.update(io_relay, 5000, "/downloads/liger.ino.nodemcu.bin");
}
// ---------------------------------------------------------------- //
// -------------------------- websockets -------------------------- //
// ---------------------------------------------------------------- //
char is_command[10] = "";
//char command[50]="";
char ir_code_str[7]="";

void webSocketEvent(WStype_t type, uint8_t * payload, size_t lenght) {
  switch (type) {
    case WStype_DISCONNECTED:
      Serial.println("[WSc] Disconnected!\n");
      wsConnected = false;
      got_token = false;
      break;
    case WStype_CONNECTED:
      {
        Serial.printf("[WSc] Connected to url: %s\n",  payload);
        wsConnected = true;
        response_time = now();
        // send message to server when Connected
        //char data[200] = "hello from ";
        //strcat(data, current_ssid);
        //webSocket.sendTXT(data);
        break;
      }
    case WStype_TEXT:
      {
      StaticJsonBuffer<200> jsonBuffer;
      WiFi.macAddress(mac);
      strcpy(response, (char *)payload);
      Serial.println(response);
      //JsonObject& json = parse_json(response);
      JsonObject& json = jsonBuffer.parseObject(response);
      const char* command = json["command"];
      double sendIR_str = json["sendIR"];
      const char* token_str = json["token"];
      bool update = json["update"];
      if (update) {
        http_update();
        Serial.println("HTTP UPDATE!");
        
      }
      Serial.println(token_str);
      if (token_str) {
        Serial.print("setting token | ");
        Serial.println(token_str);
        strcpy(token, token_str);
        got_token = true;
      }
      if (sendIR_str) {
        unsigned int IR_code = json["sendIR"][0];
        sendIR(IR_code);
      }
      /*char* command = strtok(response, ",");
      while (command != 0)
      {
        // Find the next command in input string
        command = strtok(0, "&");
      }
      strncpy(is_token, response, 5);
      if (strcmp(is_token, "token") == 0) {
        for (int i = 0; i < sizeof(response); i++) {
          response_token[i] = response[i + 5];
        }
        Serial.print("setting token | ");
        Serial.println(response_token);
        strcpy(token, response_token);
        got_token = true;
      }

      strncpy(is_command, response, 7);
      if (strcmp(is_command, "command") == 0) {
        for (int i = 0; i < 10; i++) {
          command[i] = response[i + 7];
        }
        if (strcmp(command,"sendIR")==0) {
          for (int i = 0; i < 8; i++) {
            ir_code_str[i] = response[i + 13];
            Serial.print("Sending IR: ");
            Serial.println(ir_code_str);
          }
          Serial.println("OPENING!");
          digitalWrite(RELAY,1);
          delay(500);
          digitalWrite(RELAY,0);
        }
        if (strcmp(command,"open")==0) {
          Serial.println("OPENING!");
          digitalWrite(RELAY,1);
          delay(500);
          digitalWrite(RELAY,0);
        }
        if (strcmp(command,"mute")==0) {
          Serial.println("MUTE!");
          unsigned int ir_code = 0x4BB6A05F;
          sendIR(ir_code);
        }
        if (strcmp(command,"close")==0) {
          Serial.println("CLOSING!");
          digitalWrite(RELAY,1);
          delay(500);
          digitalWrite(RELAY,0);
        }
        if (strcmp(command,"test_siren")==0) {
          Serial.println("TESTING SIREN!");
          digitalWrite(RELAY,1);
          delay(500);
          digitalWrite(RELAY,0);
        }
      }
      
      if (strcmp(command, "png_test") == 0) {
        Serial.println("received ping");
        response_time = now();
      }*/
      
      break;
      }
    case WStype_BIN:
      Serial.printf("[WSc] get binary lenght: %u\n", lenght);
      hexdump(payload, lenght);
      // webSocket.sendBIN(payload, lenght);
      break;
  }
}

// ---------------------------------------------------------------- //
// ----------------------- ultra-sonic sensor --------------------- //
// ---------------------------------------------------------------- //
void get_distance() {
  distance_delta = (old_distance - distance)*(old_distance - distance);
  if (distance_delta > 10000 ) {
    old_distance = distance;    
    String(now()).toCharArray(uptime, 10);
    String(distance).toCharArray(distance_str, 50);
    strcpy(message, "{ \"mac\":\"");
    strcat(message, mac_addr);
    strcat(message, "\", \"device_type\":");
    strcat(message, "\"garage_opener\", ");
    strcat(message,"\"local_ip\":\"");
    strcat(message, local_ip);
    strcat(message, "\", \"uptime\":");
    strcat(message, uptime);
    strcat(message, ", \"distance\":");
    strcat(message, distance_str);
    strcat(message, ", \"token\":\"");
    strcat(message, token);
    strcat(message, "\", \"analog\":\"");
    //strcat(message,analog_data_str);
    strcat(message, "\" }");
    Serial.println(message);
    webSocket.sendTXT(message);
  }
}

int echo_count = 0;
int count_max = 40;
void trigger_pulse()
{
  digitalWrite(TRIGGER, LOW);
  delayMicroseconds(2);
  
  digitalWrite(TRIGGER, HIGH);
  delayMicroseconds(10); 
  
  digitalWrite(TRIGGER, LOW);
  duration = pulseIn(ECHO, HIGH);
  distance_buffer = (duration/2) / 29.1;
  distance_sum += distance_buffer;
  if (count >= count_max) {
    distance = distance_sum/count_max;
    distance_sum = 0;
    count = 0;    
  }
  count++;
  //Serial.print(distance);
  //Serial.println("cm");
}

// ---------------------------------------------------------------- //
// ------------------------ IR tx and rx -------------------------- //
// ---------------------------------------------------------------- //
IRsend irsend(IR_TX);
IRrecv irrecv(IR_RX);
void sendIR(unsigned int ir_code) {
  Serial.print("Sending IR: ");
  Serial.println(ir_code,HEX);
  irsend.sendNEC(ir_code,32);
  //delay(500);
}

void receiveIR() {
  if (irrecv.decode(&results)) {
    Serial.print("received IR: ");
    //Serial.println(results.value, HEX);
    irrecv.resume(); // Receive the next value
    char ir_code[10];
    //sprintf(ir_code, "%02x",results.value);
    sprintf(ir_code, "%d",results.value);
    Serial.println(ir_code);
    String(now()).toCharArray(uptime, 10);
    String(distance).toCharArray(distance_str, 50);
    strcpy(message, "{ \"mac\":\"");
    strcat(message, mac_addr);
    strcat(message, "\", \"device_type\":");
    strcat(message, "\"media_controller\", ");
    strcat(message,"\"local_ip\":\"");
    strcat(message, local_ip);
    strcat(message, "\", \"uptime\":");
    strcat(message, uptime);
    strcat(message, ", \"token\":\"");
    strcat(message, token);
    strcat(message, "\", \"ir_code\":");
    strcat(message,ir_code);
    strcat(message, " }");
    Serial.println(message);
    webSocket.sendTXT(message);
  }
  //sendIR(&results);
  delay(100);
}

// ---------------------------------------------------------------- //
// ------------------------- microphone --------------------------- //
// ---------------------------------------------------------------- //
long previousMillis = 0;        // will store last time LED was updated
long interval = 1000;
int total = 0;
int sample = 0;
const int sample_size = 100;
int audio_buffer[sample_size];
int bias = 0;
int magnitude = 0;

void fft(int audio_buffer[]) {
  for (int i = 0; i < sample_size; i++) {
    magnitude+=magnitude;
    Serial.print(audio_buffer[i]);
    Serial.print("|");
  }
  Serial.println();
}

void read_mic() {
  t0 = micros();
  for (int i = 0; i < sample_size; i++) {
    sample = analogRead(A0);
    magnitude += (sample - bias)*(sample - bias);
    total += sample;
    audio_buffer[i] = sample;
    //fft(audio_buffer);
    delay(1);
  }
  t = micros()-t0;  // calculate elapsed time
  magnitude = magnitude / sample_size;
  bias = total / sample_size;
  if (magnitude > 200) {
    Serial.print("Sampling frequency: ");
    Serial.print((float)1000000/t);
    Serial.print(" KHz | ");
    Serial.print("magnitude: ");
    Serial.println(magnitude);

    String(now()).toCharArray(now_str, 10);
    String(magnitude).toCharArray(magnitude_str, 50);
    String(PIR_t).toCharArray(PIR_width_str, 50);    
    motion_status.toCharArray(motion_status_str, 50);
    strcpy(message, "{ \"mac\":\"");
    strcat(message, mac_addr);
    strcat(message, "\", \"device_type\":");
    strcat(message, "[\"room_sensor\"],");
    strcat(message,"\"local_ip\":\"");
    strcat(message, local_ip);
    strcat(message, "\", \"uptime\":");
    strcat(message, now_str);
    strcat(message, ", \"motion\":\"");
    strcat(message, motion_status_str);
    strcat(message, "\", \"PIR_width\":");
    strcat(message, PIR_width_str);
    strcat(message, ", \"magnitude\":");
    strcat(message, magnitude_str);
    strcat(message, ", \"token\":\"");
    strcat(message, token);
    strcat(message, "\", \"data\":\"");
    //strcat(message,analog_data_str);
    strcat(message, "\" }");
    Serial.println(message);
    webSocket.sendTXT(message);    
  }
  total = 0;
  magnitude = 0;
  //Serial.println(audio_buffer[numSamples]);
  /*if (numSamples>=sample_size)
  {
  }*/

  
  /*unsigned long currentMillis = millis();
 
  if(currentMillis - previousMillis > interval) {
    // save the last time you blinked the LED 
    previousMillis = currentMillis;   
 
    // if the LED is off turn it on and vice-versa:
    if (ledState == LOW)
      ledState = HIGH;
    else
      ledState = LOW;
 
    // set the LED with the ledState of the variable:
    //digitalWrite(ledPin, ledState);
  }*/
  /* 
  int sample_rate = 20;
  int sample_size = sample_rate;
  int bias = 432;
  magnitude = 0;
  int raw_sound[sample_size];
  yield();
  int start_time = micros();
  for (int i = 0; i < sample_rate; i++) {
    delayMicroseconds(110);
    //delayMicroseconds(1000);
    //raw_sound[i] = analogRead(A0);
    //magnitude += (analogRead(A0) - bias)*(analogRead(A0) - bias);
    int val = analogRead(A0);
    magnitude += val^2;
  }
  magnitude = magnitude / sample_rate;
  int tested_sample_rate = micros() - start_time;
  tested_sample_rate = tested_sample_rate / sample_rate;
  tested_sample_rate = tested_sample_rate * 10^6;
  
  Serial.print("sample rate: " );
  Serial.print(tested_sample_rate);
  Serial.println(" samples/second" );
  if ( magnitude > 20 ) {
    char now_str[10] = "";
    char magnitude_str[50] = "";
    String(now()).toCharArray(now_str, 10);
    String(magnitude).toCharArray(magnitude_str, 50);
    strcpy(message, "{ \"mac\":\"");
    strcat(message, mac_addr);
    strcat(message, "\", \"device_type\":");
    strcat(message, "[\"room_sensor\"],");
    strcat(message,"\"local_ip\":\"");
    strcat(message, local_ip);
    strcat(message, "\", \"uptime\":");
    strcat(message, now_str);
    strcat(message, ", \"magnitude\":");
    strcat(message, magnitude_str);
    strcat(message, ", \"token\":\"");
    strcat(message, token);
    strcat(message, "\", \"data\":\"");
    //strcat(message,analog_data_str);
    strcat(message, "\" }");
    Serial.println(message);
    webSocket.sendTXT(message);      
  }*/
}

// ---------------------------------------------------------------- //
// ---------------- webserver http://192.168.4.1 ------------------ //
// ---------------------------------------------------------------- //
void handleRoot() {
  server.send(200, "text/html", html);
}

void handleSensor() {
  digitalWrite ( led, 1 );
  char temp[400];
  int sec = millis() / 1000;
  int min = sec / 60;
  int hr = min / 60;
  snprintf ( temp, 400,
             "<html>\
  <head>\
    <meta http-equiv='refresh' content='5'/>\
    <title>ESP8266 Demo</title>\
    <style>\
      body { background-color: #cccccc; font-family: Arial, Helvetica, Sans-Serif; Color: #000088; }\
    </style>\
  </head>\
  <body>\
    <h1>Hello from ESP8266!</h1>\
    <p>Uptime: %02d:%02d:%02d</p>\
    <img src=\"/test.svg\" />\
  </body>\
</html>",
             hr, min % 60, sec % 60
           );
  server.send ( 200, "text/html", temp );
  digitalWrite ( led, 0 );
}

void handleNotFound() {
  digitalWrite ( led, 1 );
  String message = "File Not Found\n\n";
  message += "URI: ";
  message += server.uri();
  message += "\nMethod: ";
  message += ( server.method() == HTTP_GET ) ? "GET" : "POST";
  message += "\nArguments: ";
  message += server.args();
  message += "\n";
  for ( uint8_t i = 0; i < server.args(); i++ ) {
    message += " " + server.argName ( i ) + ": " + server.arg ( i ) + "\n";
  }
  server.send ( 404, "text/plain", message );
  digitalWrite ( led, 0 );
}

void drawGraph() {
  String out = "";
  char temp[100];
  out += "<svg xmlns=\"http://www.w3.org/2000/svg\" version=\"1.1\" width=\"400\" height=\"150\">\n";
  out += "<rect width=\"400\" height=\"150\" fill=\"rgb(250, 230, 210)\" stroke-width=\"1\" stroke=\"rgb(0, 0, 0)\" />\n";
  out += "<g stroke=\"black\">\n";
  int y = rand() % 130;
  for (int x = 10; x < 390; x += 10) {
    int y2 = rand() % 130;
    sprintf(temp, "<line x1=\"%d\" y1=\"%d\" x2=\"%d\" y2=\"%d\" stroke-width=\"1\" />\n", x, 140 - y, x + 10, 140 - y2);
    out += temp;
    y = y2;
  }
  out += "</g>\n</svg>\n";
  server.send ( 200, "image/svg+xml", out);
}

// ---------------------------------------------------------------- //
// ---------------------- wifi managment -------------------------- //
// ---------------------------------------------------------------- //
void store_wifi() {
  int j = 0;
  int i = 0;
  ssid_ptr = 0;

  strcpy(ssid, server.arg(0).c_str());
  strcpy(password, server.arg(1).c_str());
  char html2[500] = "";
  Serial.print("stored | SSID (");
  Serial.print(ssid);
  Serial.print(")  PASSWORD (");
  Serial.print(password);
  Serial.print(")\n");
  strcat(html2, "connecting to ");
  strcat(html2, ssid);
  strcat(html2, " with ");
  strcat(html2, password);
  strcat(html2, "<br><br>Enter your device ID (<b>");
  strcat(html2,mac_addr);  
  strcat(html2, "</b>) at <a href='http://pyfi.org'>pyfi.org</a>");
  server.send(200, "text/html", html2);
  
  Serial.println(ssid);
  Serial.println(password);
  for (int i = 0; i < 100; i++) //clear some memory
    EEPROM.write(i, 0);

  for (i = 0; i < sizeof(ssid) ; i++) {
    if (ssid[i]) {
      Serial.print(" (loop) ");
      Serial.print(i);
      Serial.print(" ");
      Serial.println(ssid[i]);
      EEPROM.write(i, ssid[i]);
    } else {
      j = i;
      i = sizeof(ssid);
    }
  }
  Serial.print(" (adding) ");
  Serial.print(j);
  Serial.println(" null ");
  EEPROM.write(j, 0);
  j++;
  for (i = 0; i < sizeof(password) ; i++, j++) {
    if (password[i]) {
      Serial.print(" (loop) ");
      Serial.print(j);
      Serial.print(" ");
      Serial.println(password[i]);
      EEPROM.write(j, password[i]);
    } else {
      i = sizeof(password);
    }
  }
  Serial.print(" (adding) ");
  Serial.print(j);
  Serial.println(" null ");
  EEPROM.write(j, 0);
  EEPROM.commit();
  Serial.println((char)EEPROM.read(j + 1));

  if (ap_connect()) {
    Serial.println("connected to wifi");
    isConnected = true;
  } else {
    Serial.print("could not connect, starting access point (");
    Serial.print(mac_addr);
    Serial.println(")...");
    start_ap();
    isConnected = false;
  }
}
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
void loop() {
  //put in interrupt
  if (digitalRead(SW)) {
    Serial.println("Front switch pressed!");
    digitalWrite(SW_LED, 0);
    digitalWrite(RELAY, 1);
    button_press_time = now() - button_start_time;
    Serial.println(button_press_time);
    if (button_press_time > 10) {
      while(1); //software reset
    }
  } else {
    button_start_time = now();
    digitalWrite(RELAY,0);
  }
  
  server.handleClient();
  if (isConnected) {
    webSocket.loop();
  }
  
  /*time_delta = now() - previous_uptime;
  if (time_delta > 60) {
    send_ping();
    time_delta = 0;
    previous_uptime = now();
    response_delay = now() - response_time;
    //Serial.println(response_delay);
    if (response_delay > 120) {
      Serial.println("no response from server\n");
      webSocket.disconnect();
      webSocket.begin(io_relay, 4000);
      wsConnected = false;      
      got_token = false;
    }
  }*/
  
  if (got_token && wsConnected) {
    detect_motion();
    //read_mic();
    receiveIR();
    //get_distance();
    //trigger_pulse();
  } else {
    
    get_token();
    send_device_info();
  }
  
  delay(1);
}

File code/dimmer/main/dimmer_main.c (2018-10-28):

/* UART Echo Example

   This example code is in the Public Domain (or CC0 licensed, at your option.)

   Unless required by applicable law or agreed to in writing, this
   software is distributed on an "AS IS" BASIS, WITHOUT WARRANTIES OR
   CONDITIONS OF ANY KIND, either express or implied.
*/
#include <stdio.h>
#include <string.h>
#include "freertos/FreeRTOS.h"
#include "freertos/task.h"
#include "driver/uart.h"
#include "cJSON.h"
#include <stdlib.h>
#include "freertos/queue.h"
#include "driver/gpio.h"

#include "esp_types.h"
#include "freertos/FreeRTOS.h"
#include "freertos/task.h"
#include "freertos/queue.h"
#include "soc/timer_group_struct.h"
#include "driver/periph_ctrl.h"
#include "driver/timer.h"

#define TIMER_DIVIDER         16  //  Hardware timer clock divider
#define TIMER_SCALE           (TIMER_BASE_CLK / TIMER_DIVIDER)  // convert counter value to seconds
#define TEST_WITHOUT_RELOAD   0        // testing will be done without auto reload
#define TEST_WITH_RELOAD      1        // testing will be done with auto reload

#define ZERO_DETECT_IO      35
#define TRIAC_IO      2
#define ESP_INTR_FLAG_DEFAULT 0

static xQueueHandle gpio_evt_queue = NULL;
#define GPIO_INPUT_PIN_SEL  ((1ULL<<ZERO_DETECT_IO))
#define GPIO_OUTPUT_PIN_SEL  ((1ULL<<TRIAC_IO))

int max_brightness = 255;
int zerocross_count = 0;
int current_brightness = 0;
double triac_delay = 1;
double min_triac_delay = 0.0001;
double max_triac_delay = 0.0075;
bool neutral_present = false;
bool zerocross_present = false;
double sim_zerocross_delay = 0.0166; //simulated zero cross delay (1/120hz)

static void example_tg0_timer_init(int timer_idx,
    bool auto_reload, double timer_interval_sec);

// sets delay from when zerocross is detected and
// triac is turned off to when the triac is turned
// on. A longer delay means less power available.
void set_brightness(int brightness) {
  printf("set brightness %d %f\n",brightness,triac_delay);
  if (!neutral_present) {
  if (triac_delay<0.0040 && !neutral_present) {
    zerocross_present = false;
  } else if (!zerocross_present) {
    //printf("turning off triac to get zerocross %f\n",triac_delay);
    gpio_set_level(TRIAC_IO, 0);
  }
  }
  if (brightness > max_brightness) brightness = max_brightness;
  if (brightness < 0) brightness = 0;
  brightness = max_brightness - brightness;
  triac_delay = min_triac_delay + max_triac_delay*((double)brightness/max_brightness);
  current_brightness = brightness;
}

void dec_brightness(int amount) {
  int new_brightness = current_brightness - amount;
  set_brightness(new_brightness);
}

void inc_brightness(int amount) {
  int new_brightness = current_brightness + amount;
  set_brightness(new_brightness);
}

void fade_brightness(int start, int stop, int interval) {
  printf("fading from %d to %d in %dms\n",start,stop,interval);
  int divider = 3;
  interval*=divider;
  if (stop>start) {
    interval = interval / (stop - start);
    for(int i=start; i<=stop; i+=divider) {
      set_brightness(i);
      if (interval<10) interval=10;
      vTaskDelay( interval / portTICK_RATE_MS);
    }
  }

  if (start>stop) {
    interval = interval / (start - stop);
    for(int i=start; i>=stop; i-=divider) {
      set_brightness(i);
      if (interval<10) interval=10;
      vTaskDelay( interval / portTICK_RATE_MS);
    }
  }
}

typedef struct {
    int type;  // the type of timer's event
    int timer_group;
    int timer_idx;
    uint64_t timer_counter_value;
} timer_event_t;

xQueueHandle timer_queue;

static void inline print_timer_counter(uint64_t counter_value) {
    printf("Counter: 0x%08x%08x\n", (uint32_t) (counter_value >> 32),
                                    (uint32_t) (counter_value));
    printf("Time   : %.8f s\n", (double) counter_value / TIMER_SCALE);
}

void IRAM_ATTR timer_group0_isr(void *para) {
    int timer_idx = (int) para;

    /* Retrieve the interrupt status and the counter value
       from the timer that reported the interrupt */
    uint32_t intr_status = TIMERG0.int_st_timers.val;
    TIMERG0.hw_timer[timer_idx].update = 1;
    uint64_t timer_counter_value =
        ((uint64_t) TIMERG0.hw_timer[timer_idx].cnt_high) << 32
        | TIMERG0.hw_timer[timer_idx].cnt_low;

    /* Prepare basic event data
       that will be then sent back to the main program task */
    timer_event_t evt;
    evt.timer_group = 0;
    evt.timer_idx = timer_idx;
    evt.timer_counter_value = timer_counter_value;
    /* Clear the interrupt
       and update the alarm time for the timer with without reload */
    if ((intr_status & BIT(timer_idx)) && timer_idx == TIMER_0) {
        example_tg0_timer_init(TIMER_1, TEST_WITH_RELOAD, triac_delay);
        evt.type = TEST_WITHOUT_RELOAD;
        TIMERG0.int_clr_timers.t0 = 1;
        timer_counter_value += (uint64_t) (sim_zerocross_delay * TIMER_SCALE);
        TIMERG0.hw_timer[timer_idx].alarm_high = (uint32_t) (timer_counter_value >> 32);
        TIMERG0.hw_timer[timer_idx].alarm_low = (uint32_t) timer_counter_value;
        TIMERG0.hw_timer[0].config.alarm_en = TIMER_ALARM_EN;
    } else if ((intr_status & BIT(timer_idx)) && timer_idx == TIMER_1) {
        gpio_set_level(TRIAC_IO, 1);
        //TIMERG0.hw_timer[0].config.alarm_en = TIMER_ALARM_DIS;
        evt.type = TEST_WITH_RELOAD;
        TIMERG0.int_clr_timers.t1 = 1;
    } else {
        evt.type = -1; // not supported even type
    }

    /* After the alarm has been triggered
      we need enable it again, so it is triggered the next time */
    //TIMERG0.hw_timer[timer_idx].config.alarm_en = TIMER_ALARM_EN;

    xQueueSendFromISR(timer_queue, &evt, NULL);
}

static void example_tg0_timer_init(int timer_idx,
    bool auto_reload, double timer_interval_sec) {
    /* Select and initialize basic parameters of the timer */
    timer_config_t config;
    config.divider = TIMER_DIVIDER;
    config.counter_dir = TIMER_COUNT_UP;
    config.counter_en = TIMER_PAUSE;
    config.alarm_en = TIMER_ALARM_EN;
    config.intr_type = TIMER_INTR_LEVEL;
    config.auto_reload = auto_reload;
    timer_init(TIMER_GROUP_0, timer_idx, &config);

    /* Timer's counter will initially start from value below.
       Also, if auto_reload is set, this value will be automatically reload on alarm */
    timer_set_counter_value(TIMER_GROUP_0, timer_idx, 0x00000000ULL);

    /* Configure the alarm value and the interrupt on alarm. */
    timer_set_alarm_value(TIMER_GROUP_0, timer_idx, timer_interval_sec * TIMER_SCALE);
    timer_enable_intr(TIMER_GROUP_0, timer_idx);
    timer_isr_register(TIMER_GROUP_0, timer_idx, timer_group0_isr,
        (void *) timer_idx, ESP_INTR_FLAG_IRAM, NULL);

    timer_start(TIMER_GROUP_0, timer_idx);
}
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

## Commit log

2016-06-20 liger .2
    [liger.sch]
2016-06-20 liger 0.2
    [liger.sch]
2016-06-25 more datasheets
    [liger.sch]
2016-06-25 all current data sheets are done
    [liger.sch]
2016-06-27 pcb bitches
    [liger.csv, liger.sch]
2016-07-01 almost done
    [liger.kicad_pcb, liger.sch]
2016-07-03 last push
    [liger.kicad_pcb]
2016-07-20 final update
    [_saved_liger.sch, liger.sch]
2016-07-25 fixed footprint errors, reorganized
    [liger.sch]
2016-09-07 added MEMS mic
    [liger.sch]
2016-11-15 sync.sh update
    [liger-B.Cu.gbr, liger-B.Mask.gbr, liger-B.SilkS.gbr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]
2018-06-12 updated schematic
    [InfraRed.sch, PIR.sch, audio.sch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]
2018-06-12 added interface
    [Interface.sch]
2018-08-01 testing new ws code
    [partitions.csv]
2018-08-01 multifile update
    [partitions.csv]
2018-08-06 token exchange system with relay
2018-08-09 finishing up buttons, json error checking
    [main.c, pir.c]
2018-08-14 added physical button to switch function
2018-08-14 added device type "liger" to http headers
2018-08-14 fixed button service conflict
    [main.c]
2018-08-15 fixed crash in switch service
    [main.c]
2018-08-22 layout complete
    [liger.kicad_pcb]
2018-08-22 pcb complete
    [liger.kicad_pcb]
2018-08-22 final touches on silkscreen, sending off to oshpark
    [liger-B.Cu.gbr, liger-B.Mask.gbr, liger-Edge.Cuts.gbr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]
2018-08-22 add bom
    [bom.csv, liger.csv, liger.sch]
2018-08-23 order complete
    [InfraRed.sch, Interface.sch, PIR.sch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]
2018-08-26 adding binary switch driver for magnetic switch
2018-08-28 binary switch driver
    [_saved_liger.sch]
2018-08-29 added contact switch driver and service
2018-09-02 track these
2018-09-02 broken timer code
2018-09-16 created motion service that uses PIR driver
2018-09-28 update schematic
    [PIR.sch, _saved_liger.sch, liger.kicad_pcb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]
2018-10-07 update button
    [PIR.sch, liger.kicad_pcb]
2018-10-21 update model
    [liger.blend]
